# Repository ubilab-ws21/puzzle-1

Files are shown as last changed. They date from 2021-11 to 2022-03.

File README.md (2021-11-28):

# Divert power to machine room door (puzzle-1)
This puzzle is the first part of the 2021 ESCLAB.
According to that orange american man that once was US president, it's the best puzzle the world has ever seen.

## Objective
Divert the emergency power to the door that prevents you fom entering the second room.

## Story
There is some wiring on the wall. When you'll find some more panels to create the connection maybe you can divert the power to the door. Apparently the emergency power has not been used in ages.  
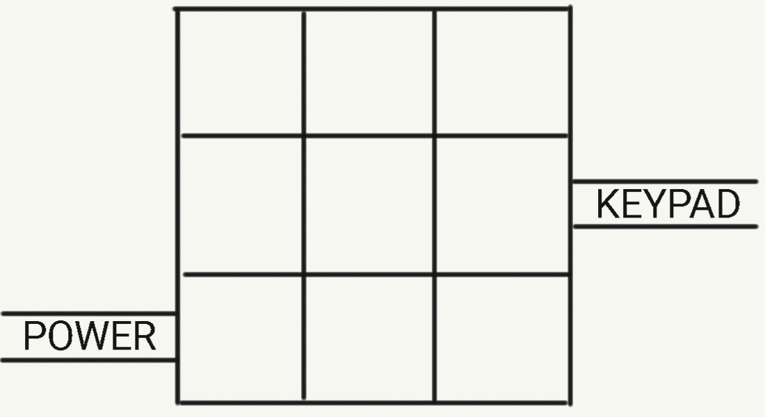
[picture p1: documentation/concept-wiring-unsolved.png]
  
You spot a cube on the table in the room thats sides look like panels that yould be used for that.  
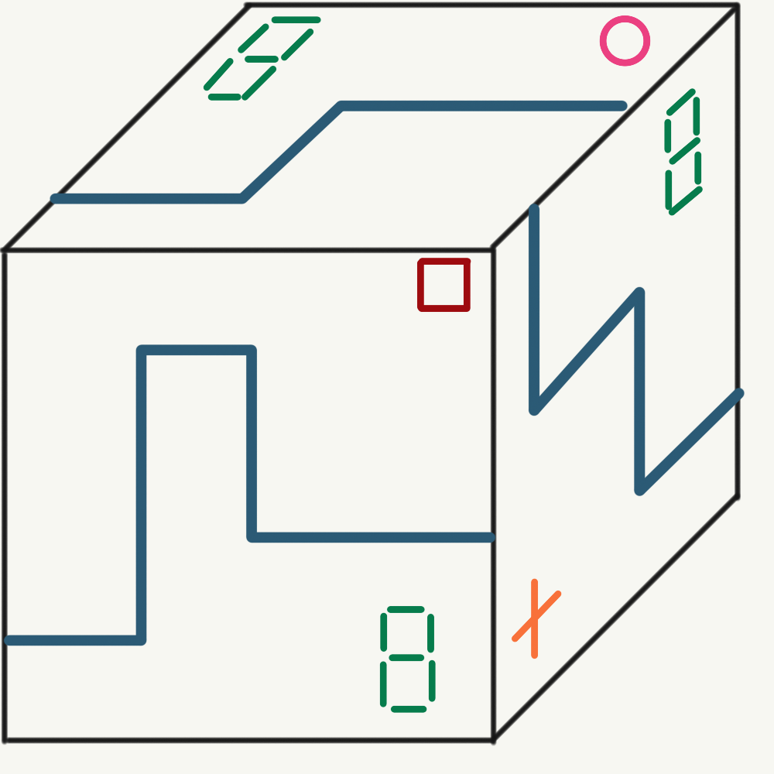
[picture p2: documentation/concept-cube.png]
  
Upon further inspection you see that the cube starts sparkling when moving it in the hand. Also there are weird symbols on each side.  
Also in the room there is some kind of comic, that has the symbols in the title and a hint "to the sun".  
Maybe placing the cube with the symbols of the comic towards the sun (top) in the correct order it will open.

After finishing the sequence the cube lights up greeen and suddenly the panels will unlatch so you can take 'em off.  
You solve the wire-maze, given by the panels and place them so the connection between "emergency power" and the keypad is created on the wall.  

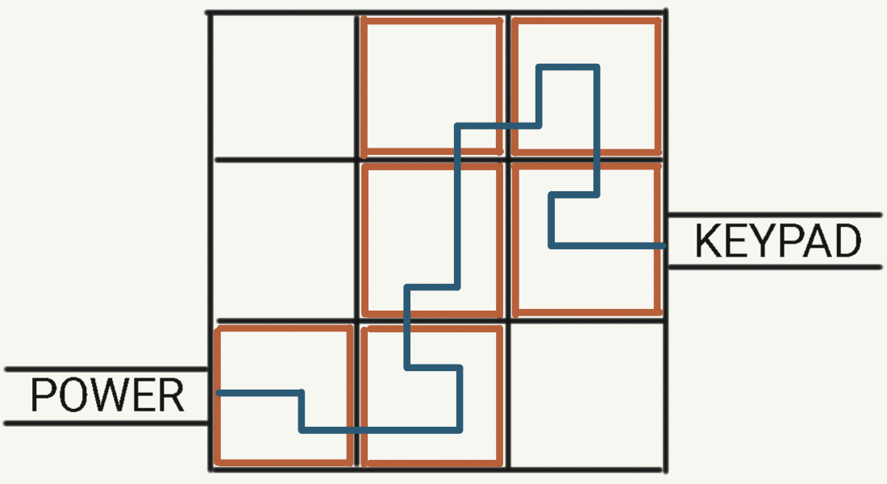
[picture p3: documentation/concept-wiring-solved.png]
  
The door opens and you step into the next room.

And then you die. Or maybe something nicer happens - that's up to the people doing the next puzzles. :)

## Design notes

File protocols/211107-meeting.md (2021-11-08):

# Protocol Meeting 07.11.2021	ESCLAB

**Autor**	Kevin Mader  
**Place & Time**	Kevin’s home, 16:00 – 20:15  
**Status**	Updated 08.11.2021  
**Attendees**	Alina, Sanjeev, Jonathan, Kevin  

## Topics

| Type | Content/Result | Name & Date |
|:----:| --- | --- |
| I |Update for Kevin about content of lab meeting from 04.11.2021<br>- Box to unlock the door to next room<br>- Has to be placed in a special orientation to be unlockable<br>- Unlocking by solving a wiring-challenge on the side of the box | |
| I | Rethinking game idea<br>- Box is small, therefore wiring -challenge would be (too) small<br>- No good story idea, why the wires should be on the box | |
| I | modification ideas for the game<br>- Box is small, therefore connection-challenge would be (too) small<br>- Insufficient ideas of how and why to orient the box<br>- Wiring could be “bypassing of a lock on the box”, not quite ubiquitous. | |
| I | Extending the game idea (Wiring)<br>- wiring-challenge will be part of the room<br>- creating the correct connection will enable the keypad at the door<br>- will be a more easy challenge<br>- box will contain needed components for wiring and has to be opened first | |
| I | Extending the game idea (design & unlocking of box)<br>- Box contains multi-color LEDs on all sides<br>- 6 Sides – 6 different Symbols<br>- Box has to be placed with the correct symbols up in a given order<br>- IDLE: Box is sleeping, no LED on.<br>- Moving the box: LEDs start to sparkle<br>- Correct placement: LEDs will flash green, then go back to sparkle<br>- Wrong placement: LEDs will flash red, lock input for x seconds.<br>- Correct order of input: LED will light up green in increasing intensity and then open. | |
| I | Updating the game idea #1 (Lazy as f* solution)<br>- Box will be simple box (wood) with a lid, containing wires for wiring-challenge | |
| I | Updating the game idea #2 (Fallback solution)<br>- Box will be simple box (wood) with a lid, containing square tiles used for wiring | |
| I | Updating the game idea #3 (Primary goal!)<br>- Box will be a 3D-printed box<br>- Side panels of the Box will be needed for wiring | |
| I | Recapitulation of presented Game-Idea
| I | Bill of materials has been written by hand | |
| T | Transfering BOM to octopart | Sanjeev, 11.11.2021 |
| T | Create Presentation of current game idea + initial 3D-Model for Cube | Kevin, 11.11.2021 |
| T | Writing down protocol | Kevin, 08.11.2021 |

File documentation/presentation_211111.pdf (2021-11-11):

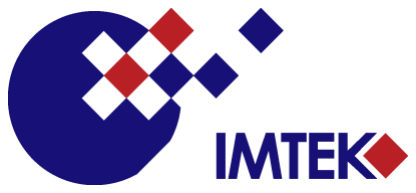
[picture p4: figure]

# Divert power to machine room door

Ubiquitous Lab - Escape Room - WS2122 11.11.2021
Institut für Mikrosystemtechnik - IMTEK Albert-Ludwigs-Universität Freiburg

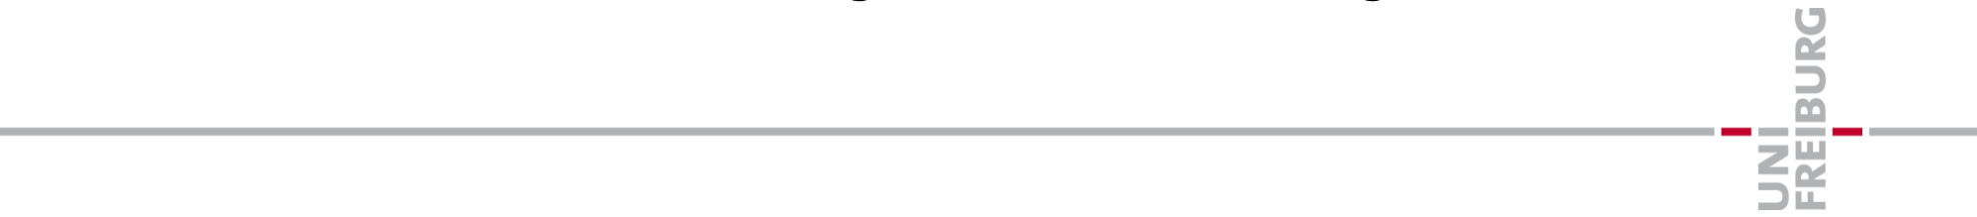
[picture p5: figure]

11.11.2021 | Kevin R. Mader

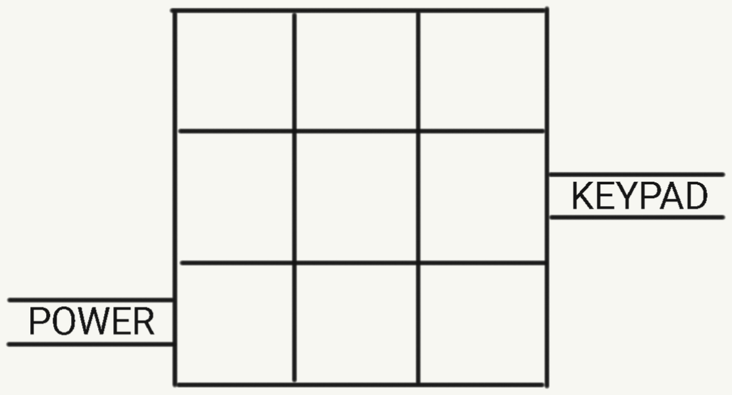
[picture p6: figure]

- 2 -

## Objective

- Divert power from USV to keypad via panel-puzzle on the wall
- 1. Find the Panels
- 2. Separate the Panels
- 3. Plug in the Panels
- 4. Enter the key code
- Enter the next room

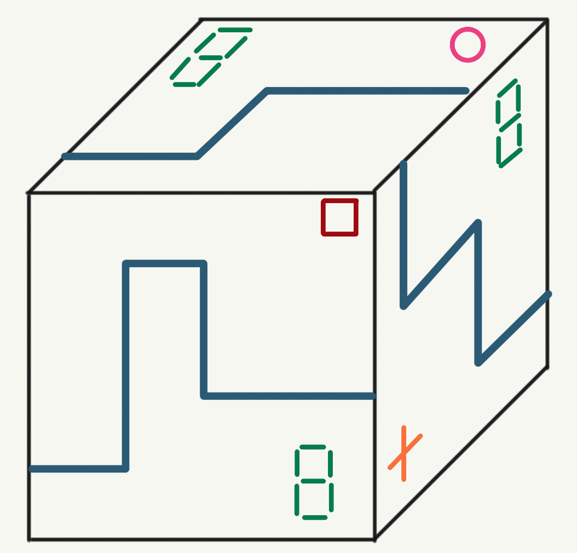
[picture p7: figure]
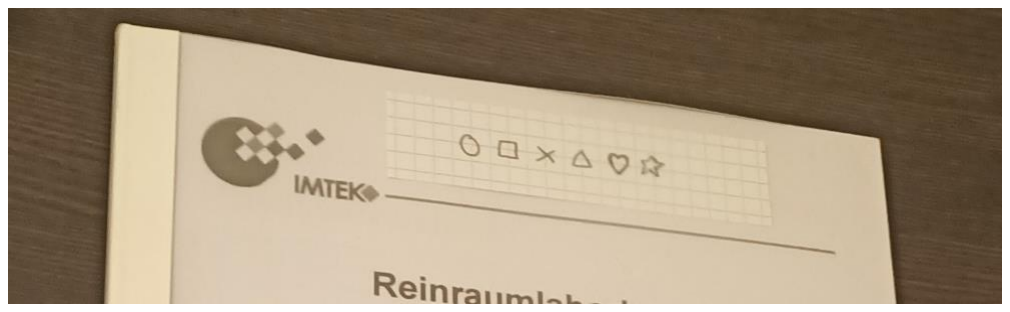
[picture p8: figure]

- 3 -

## Finding the Panels

- Mounted as a Cube
(Entrance door has not been needed a long time, so someone had some fun with them because they look nice.)
- Moving it makes it sparkle
- It has symbols on its sides
- The Symbols are on a document on the table in an order (e.g. comic, datasheet, ...)

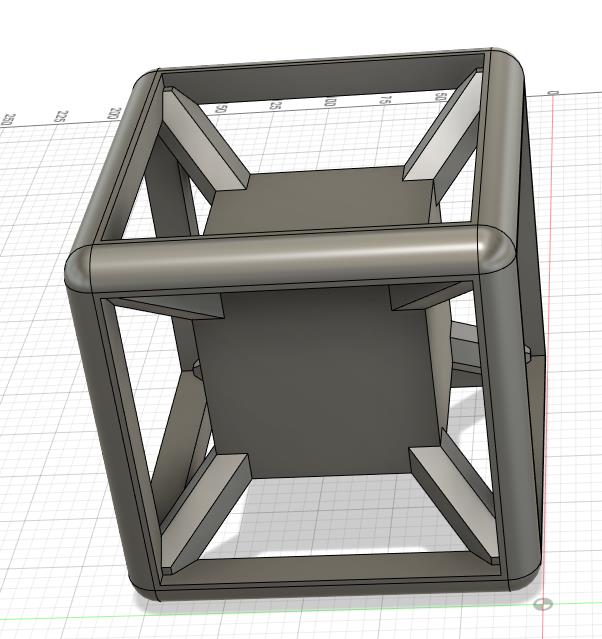
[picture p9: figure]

- 4 -

## Separating the Panels

- Moving the Cube makes it sparkle
- Placing it the correct way makes it flash green
- After finishing a sequence (given by symbols) a latch will release the panels so they can be taken out

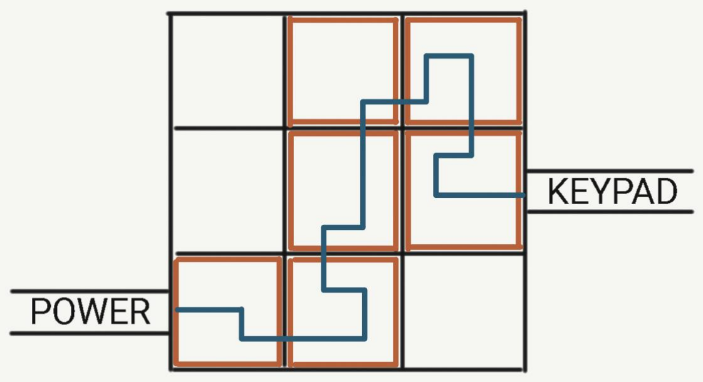
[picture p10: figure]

- 5 -

## Plug in the Panels

- Panels contain a maze
- Placing the mace so it will make connection from power to keypad
- Keypad will be aktivated
- The code can be displayed using 7-segment displays on the panels OR it can be gathered somewhere else

- 6 -

## Components / BOM

- Cube:
- 1x ESP8266 or ESP32
- 1x 3-Axis Gyroscope
- 1x stepper or servo motor
- 1x 3d-printed core with locking mechanism
- 6x 7-segment displays
- Multi-color LEDs, e.g. WS2812
- 6x 3d-printed panels (or maybe custom made PCB)
- 1x LiPo battery or stack of AA-Cells
- Wall
- 1x ESP8266 or ESP32
- 1x 3D-Printed receptables for panels
- General
- Magnets (?) for mechanical & electrical connection Alternatively Pin-header and 3D-printed locking pins
- Some wires and a lot of luck

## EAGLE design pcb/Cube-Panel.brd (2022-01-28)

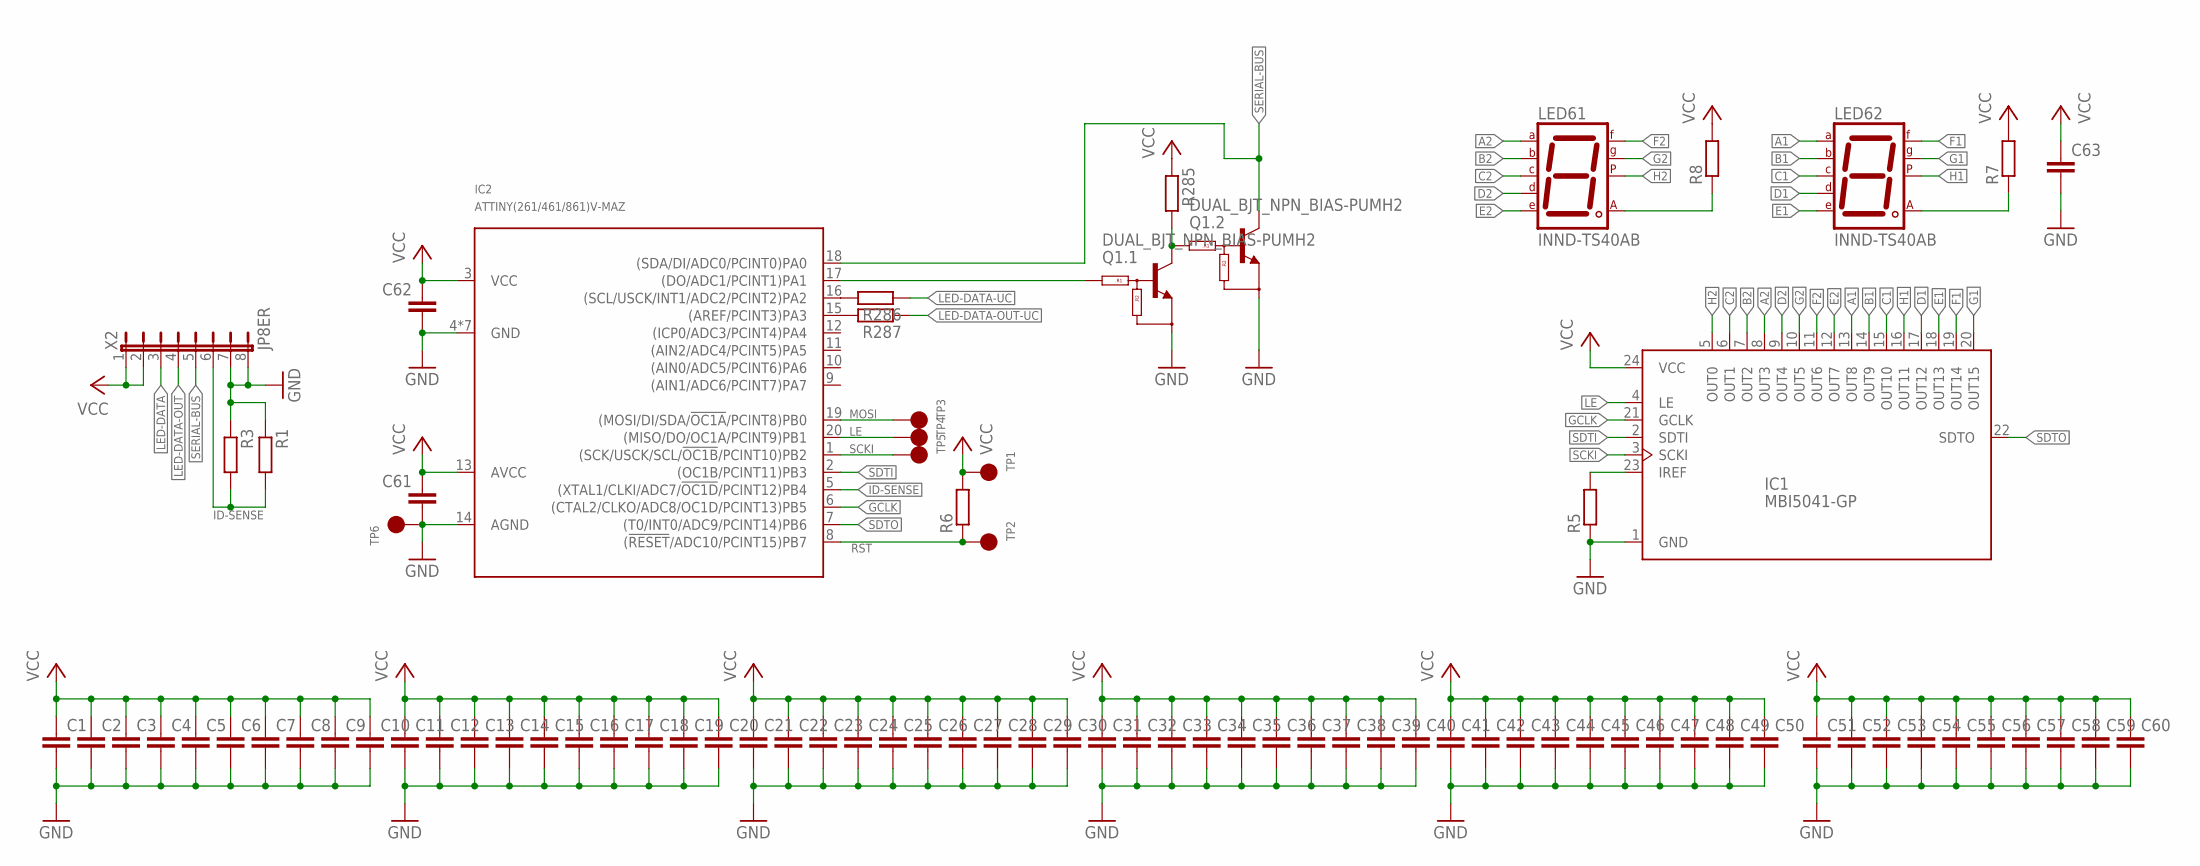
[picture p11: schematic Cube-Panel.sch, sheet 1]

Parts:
C1, C2, C3, C4, C5, C6, C7, C8, C9, C10, C11, C12, C13, C14, C15, C16, C17, C18, C19, C20, C21, C22, C23, C24, C25, C26, C27, C28, C29, C30, C31, C32, C33, C34, C35, C36, C37, C38, C39, C40, C41, C42, C43, C44, C45, C46, C47, C48, C49, C50, C51, C52, C53, C54, C55, C56, C57, C58, C59, C60, C61, C62, C63: KONDENSATOR-0603; 0603
IC1: MBI5041-GP; SSOP24-150-0.635
IC2: ATTINY(261/461/861)V-MAZ; QFN-20
LED61, LED62: INND-TS40AB; 7SEG-13
Q1: DUAL_BJT_NPN_BIAS-PUMH2; SOT-363(SC-88)
R1, R3, R5, R6, R7, R8, R285, R286, R287: WIDERSTAND-0603; 0603
TP1, TP2, TP3, TP4, TP5, TP6: TP; TP[1.5][R]
X2: JP8ER; JP8

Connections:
A1: IC1.13 (OUT8), LED62.10 (A)
A2: IC1.8 (OUT3), LED61.10 (A)
B1: IC1.14 (OUT9), LED62.9 (B)
B2: IC1.7 (OUT2), LED61.9 (B)
C1: IC1.15 (OUT10), LED62.8 (C)
C2: IC1.6 (OUT1), LED61.8 (C)
D1: IC1.17 (OUT12), LED62.5 (D)
D2: IC1.9 (OUT4), LED61.5 (D)
E1: IC1.18 (OUT13), LED62.1 (E)
E2: IC1.12 (OUT7), LED61.1 (E)
F1: IC1.19 (OUT14), LED62.2 (F)
F2: IC1.11 (OUT6), LED61.2 (F)
G1: IC1.20 (OUT15), LED62.3 (G)
G2: IC1.10 (OUT5), LED61.3 (G)
GCLK: IC1.21 (GCLK), IC2.6 ((CTAL2/CLKO/ADC8/OC1D/PCINT13)PB5)
GND: C1.P$2 (2), C2.P$2 (2), C3.P$2 (2), C4.P$2 (2), C5.P$2 (2), C6.P$2 (2), C7.P$2 (2), C8.P$2 (2), C9.P$2 (2), C10.P$2 (2), C11.P$2 (2), C12.P$2 (2), C13.P$2 (2), C14.P$2 (2), C15.P$2 (2), C16.P$2 (2), C17.P$2 (2), C18.P$2 (2), C19.P$2 (2), C20.P$2 (2), C21.P$2 (2), C22.P$2 (2), C23.P$2 (2), C24.P$2 (2), C25.P$2 (2), C26.P$2 (2), C27.P$2 (2), C28.P$2 (2), C29.P$2 (2), C30.P$2 (2), C31.P$2 (2), C32.P$2 (2), C33.P$2 (2), C34.P$2 (2), C35.P$2 (2), C36.P$2 (2), C37.P$2 (2), C38.P$2 (2), C39.P$2 (2), C40.P$2 (2), C41.P$2 (2), C42.P$2 (2), C43.P$2 (2), C44.P$2 (2), C45.P$2 (2), C46.P$2 (2), C47.P$2 (2), C48.P$2 (2), C49.P$2 (2), C50.P$2 (2), C51.P$2 (2), C52.P$2 (2), C53.P$2 (2), C54.P$2 (2), C55.P$2 (2), C56.P$2 (2), C57.P$2 (2), C58.P$2 (2), C59.P$2 (2), C60.P$2 (2), C61.P$2 (2), C62.P$2 (2), C63.P$2 (2), IC1.1 (GND), IC2.4 (GND), IC2.14 (AGND), IC2.PAD (GND), IC2.PAD$1 (GND), IC2.PAD$2 (GND), IC2.PAD$3 (GND), IC2.PAD$4 (GND), IC2.PAD$5 (GND), Q1.1 (E), Q1.4 (E), R1.P$1 (1), R3.P$1 (1), R5.P$1 (1), TP6.P$1, X2.7, X2.8; also elsewhere on the board
H1: IC1.16 (OUT11), LED62.7 (DP)
H2: IC1.5 (OUT0), LED61.7 (DP)
ID-SENSE: IC2.5 ((XTAL1/CLKI/ADC7/!OC1D!/PCINT12)PB4), R1.P$2 (2), R3.P$2 (2), X2.6
LE: IC1.4 (LE), IC2.20 ((MISO/DO/OC1A/PCINT9)PB1), TP4.P$1
LED-DATA: X2.3; also elsewhere on the board
LED-DATA-OUT: X2.4; also elsewhere on the board
LED-DATA-OUT-UC: R287.P$1 (1); also elsewhere on the board
LED-DATA-UC: R286.P$1 (1); also elsewhere on the board
MOSI: IC2.19 ((MOSI/DI/SDA/!OC1A!/PCINT8)PB0), TP3.P$1
unnamed: IC1.23 (IREF), R5.P$2 (2)
unnamed: IC2.16 ((SCL/USCK/INT1/ADC2/PCINT2)PA2), R286.P$2 (2)
unnamed: Q1.5 (B), Q1.6 (C), R285.P$2 (2)
unnamed: IC2.15 ((AREF/PCINT3)PA3), R287.P$2 (2)
unnamed: LED61.6 (CA2), R8.P$1 (1)
unnamed: LED62.6 (CA2), R7.P$1 (1)
RST: IC2.8 ((!RESET!/ADC10/PCINT15)PB7), R6.P$1 (1), TP2.P$1
SCKI: IC1.3 (SCKI), IC2.1 ((SCK/USCK/SCL/!OC1B!/PCINT10)PB2), TP5.P$1
SDTI: IC1.2 (SDTI), IC2.2 ((OC1B/PCINT11)PB3)
SDTO: IC1.22 (SDTO), IC2.7 ((T0/INT0/ADC9/PCINT14)PB6)
SERIAL-BUS: IC2.18 ((SDA/DI/ADC0/PCINT0)PA0), Q1.3 (C), X2.5
SERIAL-BUS-TX: IC2.17 ((DO/ADC1/PCINT1)PA1), Q1.2 (B)
VCC: C1.P$1 (1), C2.P$1 (1), C3.P$1 (1), C4.P$1 (1), C5.P$1 (1), C6.P$1 (1), C7.P$1 (1), C8.P$1 (1), C9.P$1 (1), C10.P$1 (1), C11.P$1 (1), C12.P$1 (1), C13.P$1 (1), C14.P$1 (1), C15.P$1 (1), C16.P$1 (1), C17.P$1 (1), C18.P$1 (1), C19.P$1 (1), C20.P$1 (1), C21.P$1 (1), C22.P$1 (1), C23.P$1 (1), C24.P$1 (1), C25.P$1 (1), C26.P$1 (1), C27.P$1 (1), C28.P$1 (1), C29.P$1 (1), C30.P$1 (1), C31.P$1 (1), C32.P$1 (1), C33.P$1 (1), C34.P$1 (1), C35.P$1 (1), C36.P$1 (1), C37.P$1 (1), C38.P$1 (1), C39.P$1 (1), C40.P$1 (1), C41.P$1 (1), C42.P$1 (1), C43.P$1 (1), C44.P$1 (1), C45.P$1 (1), C46.P$1 (1), C47.P$1 (1), C48.P$1 (1), C49.P$1 (1), C50.P$1 (1), C51.P$1 (1), C52.P$1 (1), C53.P$1 (1), C54.P$1 (1), C55.P$1 (1), C56.P$1 (1), C57.P$1 (1), C58.P$1 (1), C59.P$1 (1), C60.P$1 (1), C61.P$1 (1), C62.P$1 (1), C63.P$1 (1), IC1.24 (VCC), IC2.3 (VCC), IC2.13 (AVCC), R6.P$2 (2), R7.P$2 (2), R8.P$2 (2), R285.P$1 (1), TP1.P$1, X2.1, X2.2; also elsewhere on the board

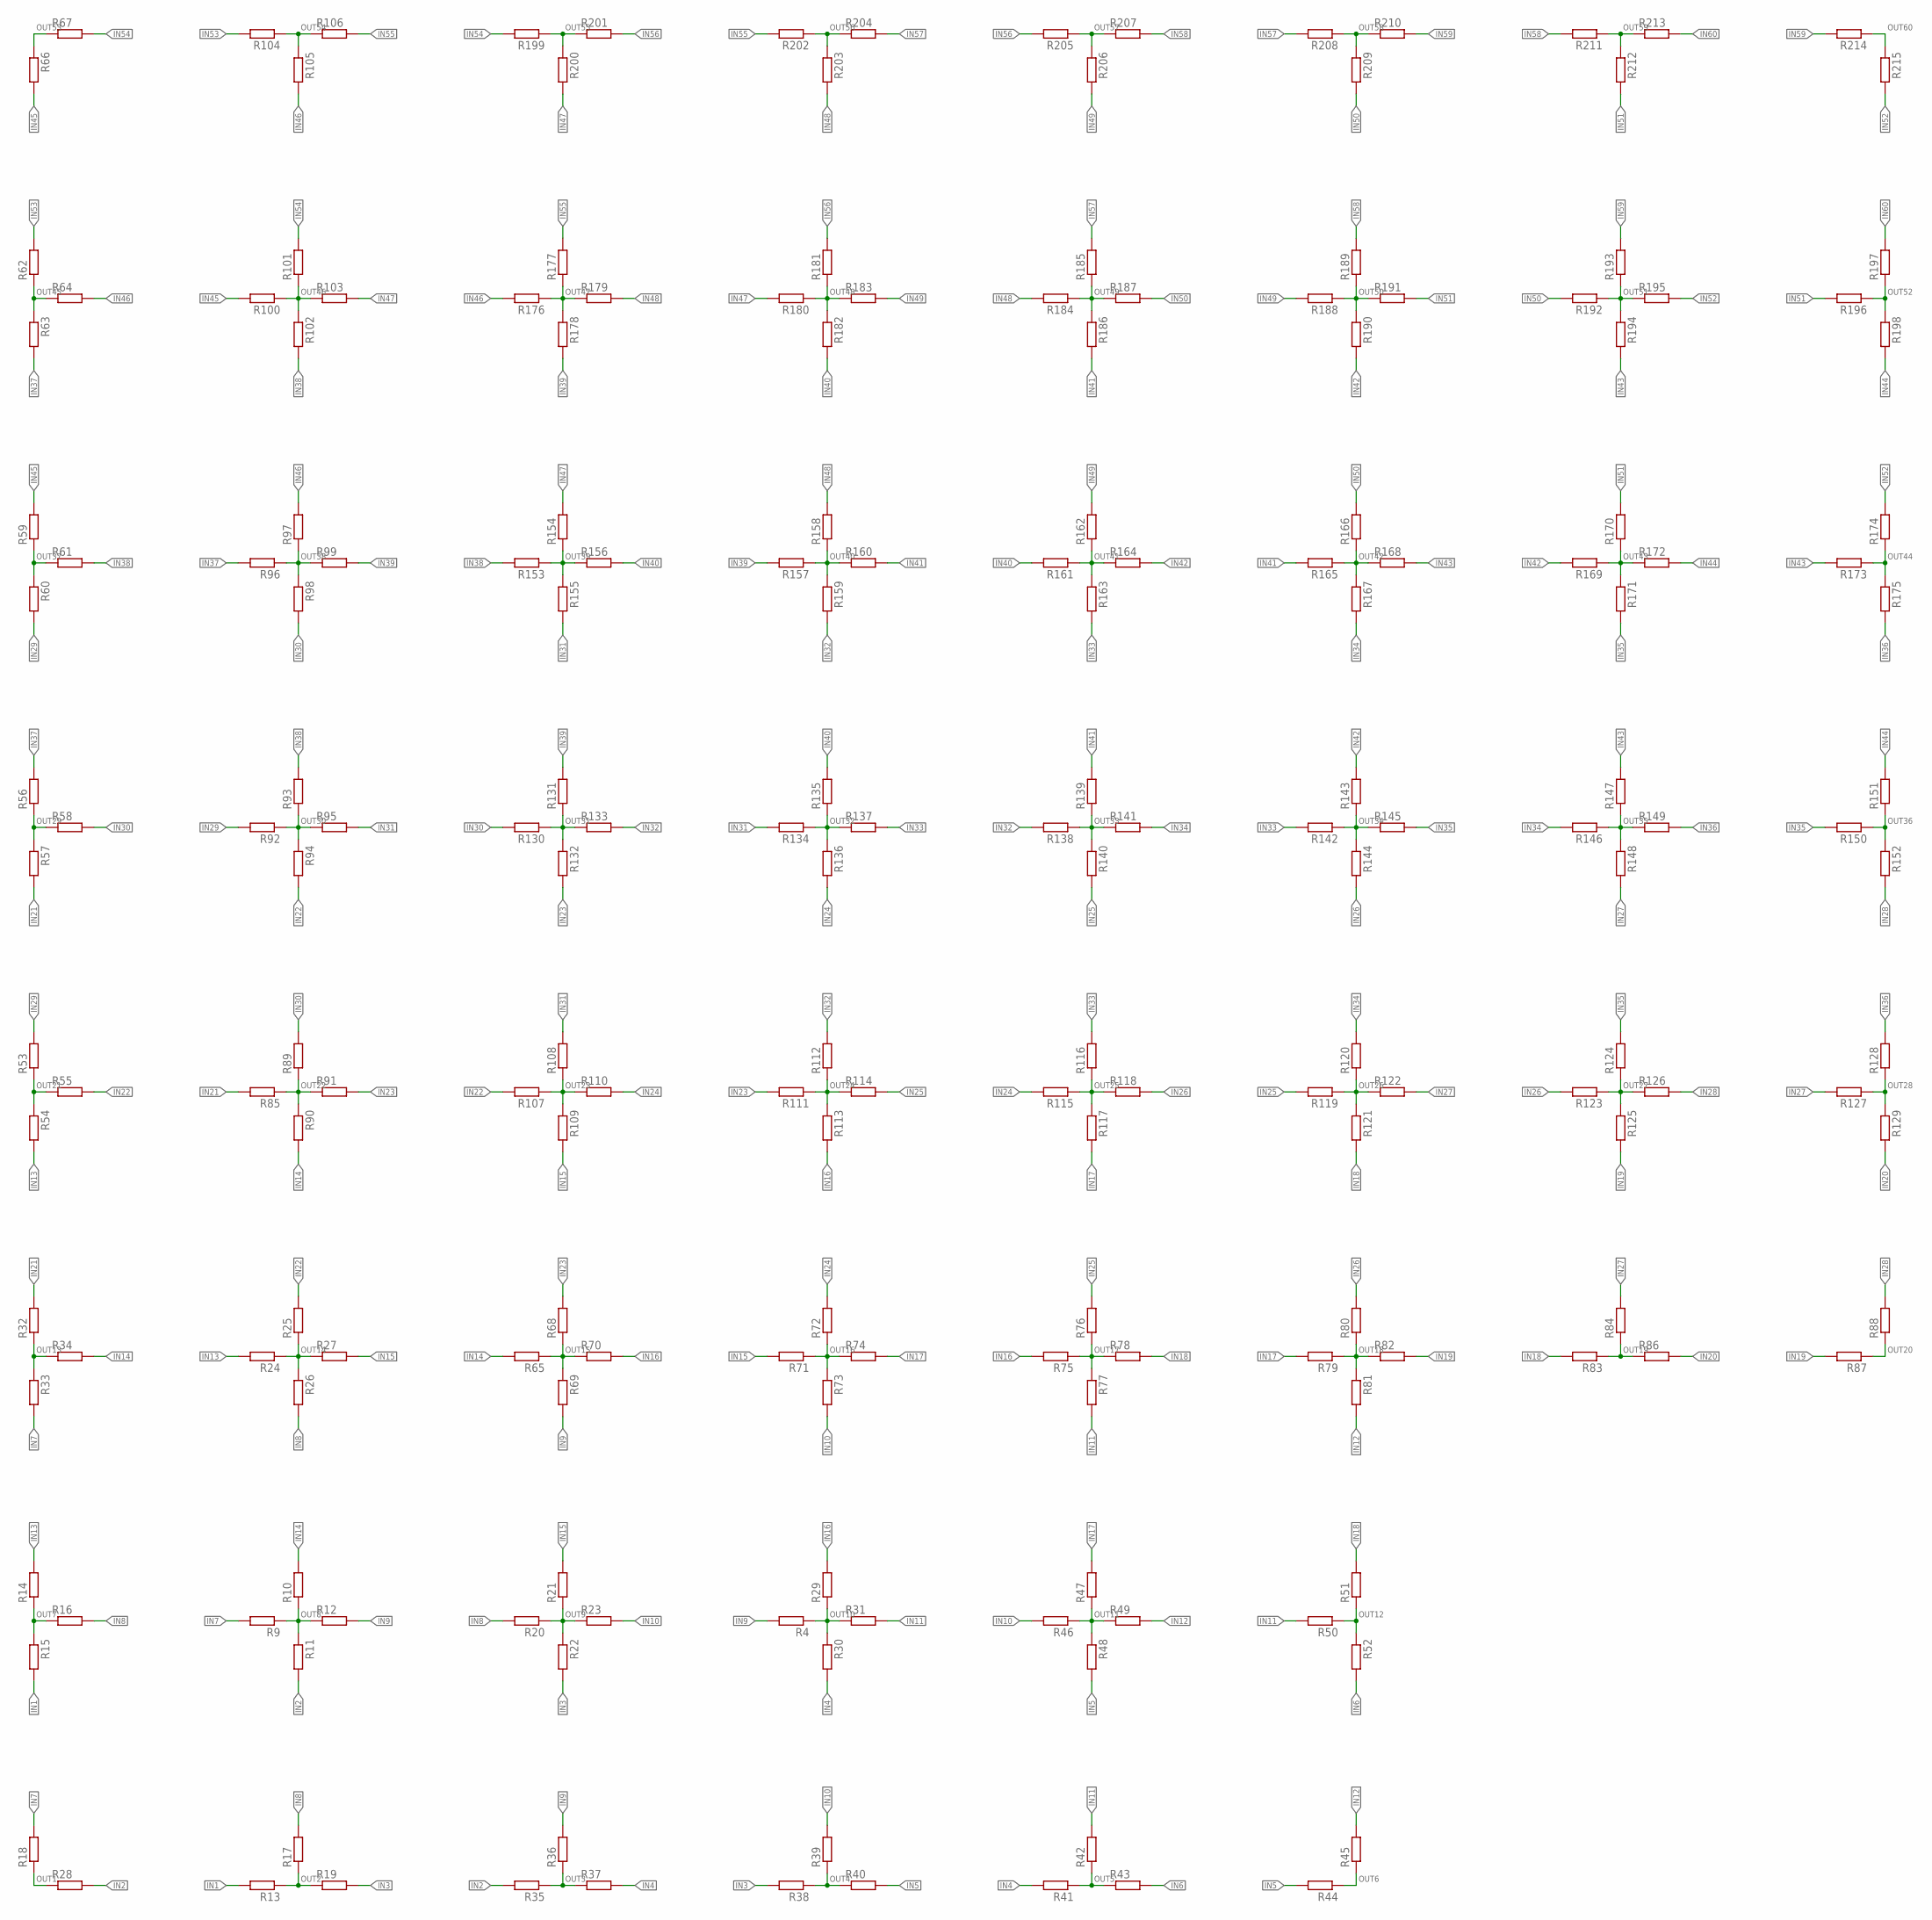
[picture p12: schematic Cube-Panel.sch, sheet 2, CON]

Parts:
R4, R9, R10, R11, R12, R13, R14, R15, R16, R17, R18, R19, R20, R21, R22, R23, R24, R25, R26, R27, R28, R29, R30, R31, R32, R33, R34, R35, R36, R37, R38, R39, R40, R41, R42, R43, R44, R45, R46, R47, R48, R49, R50, R51, R52, R53, R54, R55, R56, R57, R58, R59, R60, R61, R62, R63, R64, R65, R66, R67, R68, R69, R70, R71, R72, R73, R74, R75, R76, R77, R78, R79, R80, R81, R82, R83, R84, R85, R86, R87, R88, R89, R90, R91, R92, R93, R94, R95, R96, R97, R98, R99, R100, R101, R102, R103, R104, R105, R106, R107, R108, R109, R110, R111, R112, R113, R114, R115, R116, R117, R118, R119, R120, R121, R122, R123, R124, R125, R126, R127, R128, R129, R130, R131, R132, R133, R134, R135, R136, R137, R138, R139, R140, R141, R142, R143, R144, R145, R146, R147, R148, R149, R150, R151, R152, R153, R154, R155, R156, R157, R158, R159, R160, R161, R162, R163, R164, R165, R166, R167, R168, R169, R170, R171, R172, R173, R174, R175, R176, R177, R178, R179, R180, R181, R182, R183, R184, R185, R186, R187, R188, R189, R190, R191, R192, R193, R194, R195, R196, R197, R198, R199, R200, R201, R202, R203, R204, R205, R206, R207, R208, R209, R210, R211, R212, R213, R214, R215: WIDERSTAND-0603; 0603

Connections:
IN1: R13.P$2 (2), R15.P$2 (2); also elsewhere on the board
IN2: R11.P$2 (2), R28.P$2 (2), R35.P$2 (2); also elsewhere on the board
IN3: R19.P$2 (2), R22.P$2 (2), R38.P$2 (2); also elsewhere on the board
IN4: R30.P$2 (2), R37.P$2 (2), R41.P$2 (2); also elsewhere on the board
IN5: R40.P$2 (2), R44.P$2 (2), R48.P$2 (2); also elsewhere on the board
IN6: R43.P$2 (2), R52.P$2 (2); also elsewhere on the board
IN7: R9.P$2 (2), R18.P$2 (2), R33.P$2 (2); also elsewhere on the board
IN8: R16.P$2 (2), R17.P$2 (2), R20.P$2 (2), R26.P$2 (2); also elsewhere on the board
IN9: R4.P$2 (2), R12.P$2 (2), R36.P$2 (2), R69.P$2 (2); also elsewhere on the board
IN10: R23.P$2 (2), R39.P$2 (2), R46.P$2 (2), R73.P$2 (2); also elsewhere on the board
IN11: R31.P$2 (2), R42.P$2 (2), R50.P$2 (2), R77.P$2 (2); also elsewhere on the board
IN12: R45.P$2 (2), R49.P$2 (2), R81.P$2 (2); also elsewhere on the board
IN13: R14.P$2 (2), R24.P$2 (2), R54.P$2 (2); also elsewhere on the board
IN14: R10.P$2 (2), R34.P$2 (2), R65.P$2 (2), R90.P$2 (2); also elsewhere on the board
IN15: R21.P$2 (2), R27.P$2 (2), R71.P$2 (2), R109.P$2 (2); also elsewhere on the board
IN16: R29.P$2 (2), R70.P$2 (2), R75.P$2 (2), R113.P$2 (2); also elsewhere on the board
IN17: R47.P$2 (2), R74.P$2 (2), R79.P$2 (2), R117.P$2 (2); also elsewhere on the board
IN18: R51.P$2 (2), R78.P$2 (2), R83.P$2 (2), R121.P$2 (2); also elsewhere on the board
IN19: R82.P$2 (2), R87.P$2 (2), R125.P$2 (2); also elsewhere on the board
IN20: R86.P$2 (2), R129.P$2 (2); also elsewhere on the board
IN21: R32.P$2 (2), R57.P$2 (2), R85.P$2 (2); also elsewhere on the board
IN22: R25.P$2 (2), R55.P$2 (2), R94.P$2 (2), R107.P$2 (2); also elsewhere on the board
IN23: R68.P$2 (2), R91.P$2 (2), R111.P$2 (2), R132.P$2 (2); also elsewhere on the board
IN24: R72.P$2 (2), R110.P$2 (2), R115.P$2 (2), R136.P$2 (2); also elsewhere on the board
IN25: R76.P$2 (2), R114.P$2 (2), R119.P$2 (2), R140.P$2 (2); also elsewhere on the board
IN26: R80.P$2 (2), R118.P$2 (2), R123.P$2 (2), R144.P$2 (2); also elsewhere on the board
IN27: R84.P$2 (2), R122.P$2 (2), R127.P$2 (2), R148.P$2 (2); also elsewhere on the board
IN28: R88.P$2 (2), R126.P$2 (2), R152.P$2 (2); also elsewhere on the board
IN29: R53.P$2 (2), R60.P$2 (2), R92.P$2 (2); also elsewhere on the board
IN30: R58.P$2 (2), R89.P$2 (2), R98.P$2 (2), R130.P$2 (2); also elsewhere on the board
IN31: R95.P$2 (2), R108.P$2 (2), R134.P$2 (2), R155.P$2 (2); also elsewhere on the board
IN32: R112.P$2 (2), R133.P$2 (2), R138.P$2 (2), R159.P$2 (2); also elsewhere on the board
IN33: R116.P$2 (2), R137.P$2 (2), R142.P$2 (2), R163.P$2 (2); also elsewhere on the board
IN34: R120.P$2 (2), R141.P$2 (2), R146.P$2 (2), R167.P$2 (2); also elsewhere on the board
IN35: R124.P$2 (2), R145.P$2 (2), R150.P$2 (2), R171.P$2 (2); also elsewhere on the board
IN36: R128.P$2 (2), R149.P$2 (2), R175.P$2 (2); also elsewhere on the board
IN37: R56.P$2 (2), R63.P$2 (2), R96.P$2 (2); also elsewhere on the board
IN38: R61.P$2 (2), R93.P$2 (2), R102.P$2 (2), R153.P$2 (2); also elsewhere on the board
IN39: R99.P$2 (2), R131.P$2 (2), R157.P$2 (2), R178.P$2 (2); also elsewhere on the board
IN40: R135.P$2 (2), R156.P$2 (2), R161.P$2 (2), R182.P$2 (2); also elsewhere on the board
IN41: R139.P$2 (2), R160.P$2 (2), R165.P$2 (2), R186.P$2 (2); also elsewhere on the board
IN42: R143.P$2 (2), R164.P$2 (2), R169.P$2 (2), R190.P$2 (2); also elsewhere on the board
IN43: R147.P$2 (2), R168.P$2 (2), R173.P$2 (2), R194.P$2 (2); also elsewhere on the board
IN44: R151.P$2 (2), R172.P$2 (2), R198.P$2 (2); also elsewhere on the board
IN45: R59.P$2 (2), R66.P$2 (2), R100.P$2 (2); also elsewhere on the board
IN46: R64.P$2 (2), R97.P$2 (2), R105.P$2 (2), R176.P$2 (2); also elsewhere on the board
IN47: R103.P$2 (2), R154.P$2 (2), R180.P$2 (2), R200.P$2 (2); also elsewhere on the board
IN48: R158.P$2 (2), R179.P$2 (2), R184.P$2 (2), R203.P$2 (2); also elsewhere on the board
IN49: R162.P$2 (2), R183.P$2 (2), R188.P$2 (2), R206.P$2 (2); also elsewhere on the board
IN50: R166.P$2 (2), R187.P$2 (2), R192.P$2 (2), R209.P$2 (2); also elsewhere on the board
IN51: R170.P$2 (2), R191.P$2 (2), R196.P$2 (2), R212.P$2 (2); also elsewhere on the board
IN52: R174.P$2 (2), R195.P$2 (2), R215.P$2 (2); also elsewhere on the board
IN53: R62.P$2 (2), R104.P$2 (2); also elsewhere on the board
IN54: R67.P$2 (2), R101.P$2 (2), R199.P$2 (2); also elsewhere on the board
IN55: R106.P$2 (2), R177.P$2 (2), R202.P$2 (2); also elsewhere on the board
IN56: R181.P$2 (2), R201.P$2 (2), R205.P$2 (2); also elsewhere on the board
IN57: R185.P$2 (2), R204.P$2 (2), R208.P$2 (2); also elsewhere on the board
IN58: R189.P$2 (2), R207.P$2 (2), R211.P$2 (2); also elsewhere on the board
IN59: R193.P$2 (2), R210.P$2 (2), R214.P$2 (2); also elsewhere on the board
IN60: R197.P$2 (2), R213.P$2 (2); also elsewhere on the board
OUT1: R18.P$1 (1), R28.P$1 (1); also elsewhere on the board
OUT2: R13.P$1 (1), R17.P$1 (1), R19.P$1 (1); also elsewhere on the board
OUT3: R35.P$1 (1), R36.P$1 (1), R37.P$1 (1); also elsewhere on the board
OUT4: R38.P$1 (1), R39.P$1 (1), R40.P$1 (1); also elsewhere on the board
OUT5: R41.P$1 (1), R42.P$1 (1), R43.P$1 (1); also elsewhere on the board
OUT6: R44.P$1 (1), R45.P$1 (1); also elsewhere on the board
OUT7: R14.P$1 (1), R15.P$1 (1), R16.P$1 (1); also elsewhere on the board
OUT8: R9.P$1 (1), R10.P$1 (1), R11.P$1 (1), R12.P$1 (1); also elsewhere on the board
OUT9: R20.P$1 (1), R21.P$1 (1), R22.P$1 (1), R23.P$1 (1); also elsewhere on the board
OUT10: R4.P$1 (1), R29.P$1 (1), R30.P$1 (1), R31.P$1 (1); also elsewhere on the board
OUT11: R46.P$1 (1), R47.P$1 (1), R48.P$1 (1), R49.P$1 (1); also elsewhere on the board
OUT12: R50.P$1 (1), R51.P$1 (1), R52.P$1 (1); also elsewhere on the board
OUT13: R32.P$1 (1), R33.P$1 (1), R34.P$1 (1); also elsewhere on the board
OUT14: R24.P$1 (1), R25.P$1 (1), R26.P$1 (1), R27.P$1 (1); also elsewhere on the board
OUT15: R65.P$1 (1), R68.P$1 (1), R69.P$1 (1), R70.P$1 (1); also elsewhere on the board
OUT16: R71.P$1 (1), R72.P$1 (1), R73.P$1 (1), R74.P$1 (1); also elsewhere on the board
OUT17: R75.P$1 (1), R76.P$1 (1), R77.P$1 (1), R78.P$1 (1); also elsewhere on the board
OUT18: R79.P$1 (1), R80.P$1 (1), R81.P$1 (1), R82.P$1 (1); also elsewhere on the board
OUT19: R83.P$1 (1), R84.P$1 (1), R86.P$1 (1); also elsewhere on the board
OUT20: R87.P$1 (1), R88.P$1 (1); also elsewhere on the board
OUT21: R53.P$1 (1), R54.P$1 (1), R55.P$1 (1); also elsewhere on the board
OUT22: R85.P$1 (1), R89.P$1 (1), R90.P$1 (1), R91.P$1 (1); also elsewhere on the board
OUT23: R107.P$1 (1), R108.P$1 (1), R109.P$1 (1), R110.P$1 (1); also elsewhere on the board
OUT24: R111.P$1 (1), R112.P$1 (1), R113.P$1 (1), R114.P$1 (1); also elsewhere on the board
OUT25: R115.P$1 (1), R116.P$1 (1), R117.P$1 (1), R118.P$1 (1); also elsewhere on the board
OUT26: R119.P$1 (1), R120.P$1 (1), R121.P$1 (1), R122.P$1 (1); also elsewhere on the board
OUT27: R123.P$1 (1), R124.P$1 (1), R125.P$1 (1), R126.P$1 (1); also elsewhere on the board
OUT28: R127.P$1 (1), R128.P$1 (1), R129.P$1 (1); also elsewhere on the board
OUT29: R56.P$1 (1), R57.P$1 (1), R58.P$1 (1); also elsewhere on the board
OUT30: R92.P$1 (1), R93.P$1 (1), R94.P$1 (1), R95.P$1 (1); also elsewhere on the board
OUT31: R130.P$1 (1), R131.P$1 (1), R132.P$1 (1), R133.P$1 (1); also elsewhere on the board
OUT32: R134.P$1 (1), R135.P$1 (1), R136.P$1 (1), R137.P$1 (1); also elsewhere on the board
OUT33: R138.P$1 (1), R139.P$1 (1), R140.P$1 (1), R141.P$1 (1); also elsewhere on the board
OUT34: R142.P$1 (1), R143.P$1 (1), R144.P$1 (1), R145.P$1 (1); also elsewhere on the board
OUT35: R146.P$1 (1), R147.P$1 (1), R148.P$1 (1), R149.P$1 (1); also elsewhere on the board
OUT36: R150.P$1 (1), R151.P$1 (1), R152.P$1 (1); also elsewhere on the board
OUT37: R59.P$1 (1), R60.P$1 (1), R61.P$1 (1); also elsewhere on the board
OUT38: R96.P$1 (1), R97.P$1 (1), R98.P$1 (1), R99.P$1 (1); also elsewhere on the board
OUT39: R153.P$1 (1), R154.P$1 (1), R155.P$1 (1), R156.P$1 (1); also elsewhere on the board
OUT40: R157.P$1 (1), R158.P$1 (1), R159.P$1 (1), R160.P$1 (1); also elsewhere on the board
OUT41: R161.P$1 (1), R162.P$1 (1), R163.P$1 (1), R164.P$1 (1); also elsewhere on the board
OUT42: R165.P$1 (1), R166.P$1 (1), R167.P$1 (1), R168.P$1 (1); also elsewhere on the board
OUT43: R169.P$1 (1), R170.P$1 (1), R171.P$1 (1), R172.P$1 (1); also elsewhere on the board
OUT44: R173.P$1 (1), R174.P$1 (1), R175.P$1 (1); also elsewhere on the board
OUT45: R62.P$1 (1), R63.P$1 (1), R64.P$1 (1); also elsewhere on the board
OUT46: R100.P$1 (1), R101.P$1 (1), R102.P$1 (1), R103.P$1 (1); also elsewhere on the board
OUT47: R176.P$1 (1), R177.P$1 (1), R178.P$1 (1), R179.P$1 (1); also elsewhere on the board
OUT48: R180.P$1 (1), R181.P$1 (1), R182.P$1 (1), R183.P$1 (1); also elsewhere on the board
OUT49: R184.P$1 (1), R185.P$1 (1), R186.P$1 (1), R187.P$1 (1); also elsewhere on the board
OUT50: R188.P$1 (1), R189.P$1 (1), R190.P$1 (1), R191.P$1 (1); also elsewhere on the board
OUT51: R192.P$1 (1), R193.P$1 (1), R194.P$1 (1), R195.P$1 (1); also elsewhere on the board
OUT52: R196.P$1 (1), R197.P$1 (1), R198.P$1 (1); also elsewhere on the board
OUT53: R66.P$1 (1), R67.P$1 (1); also elsewhere on the board
OUT54: R104.P$1 (1), R105.P$1 (1), R106.P$1 (1); also elsewhere on the board
OUT55: R199.P$1 (1), R200.P$1 (1), R201.P$1 (1); also elsewhere on the board
OUT56: R202.P$1 (1), R203.P$1 (1), R204.P$1 (1); also elsewhere on the board
OUT57: R205.P$1 (1), R206.P$1 (1), R207.P$1 (1); also elsewhere on the board
OUT58: R208.P$1 (1), R209.P$1 (1), R210.P$1 (1); also elsewhere on the board
OUT59: R211.P$1 (1), R212.P$1 (1), R213.P$1 (1); also elsewhere on the board
OUT60: R214.P$1 (1), R215.P$1 (1); also elsewhere on the board

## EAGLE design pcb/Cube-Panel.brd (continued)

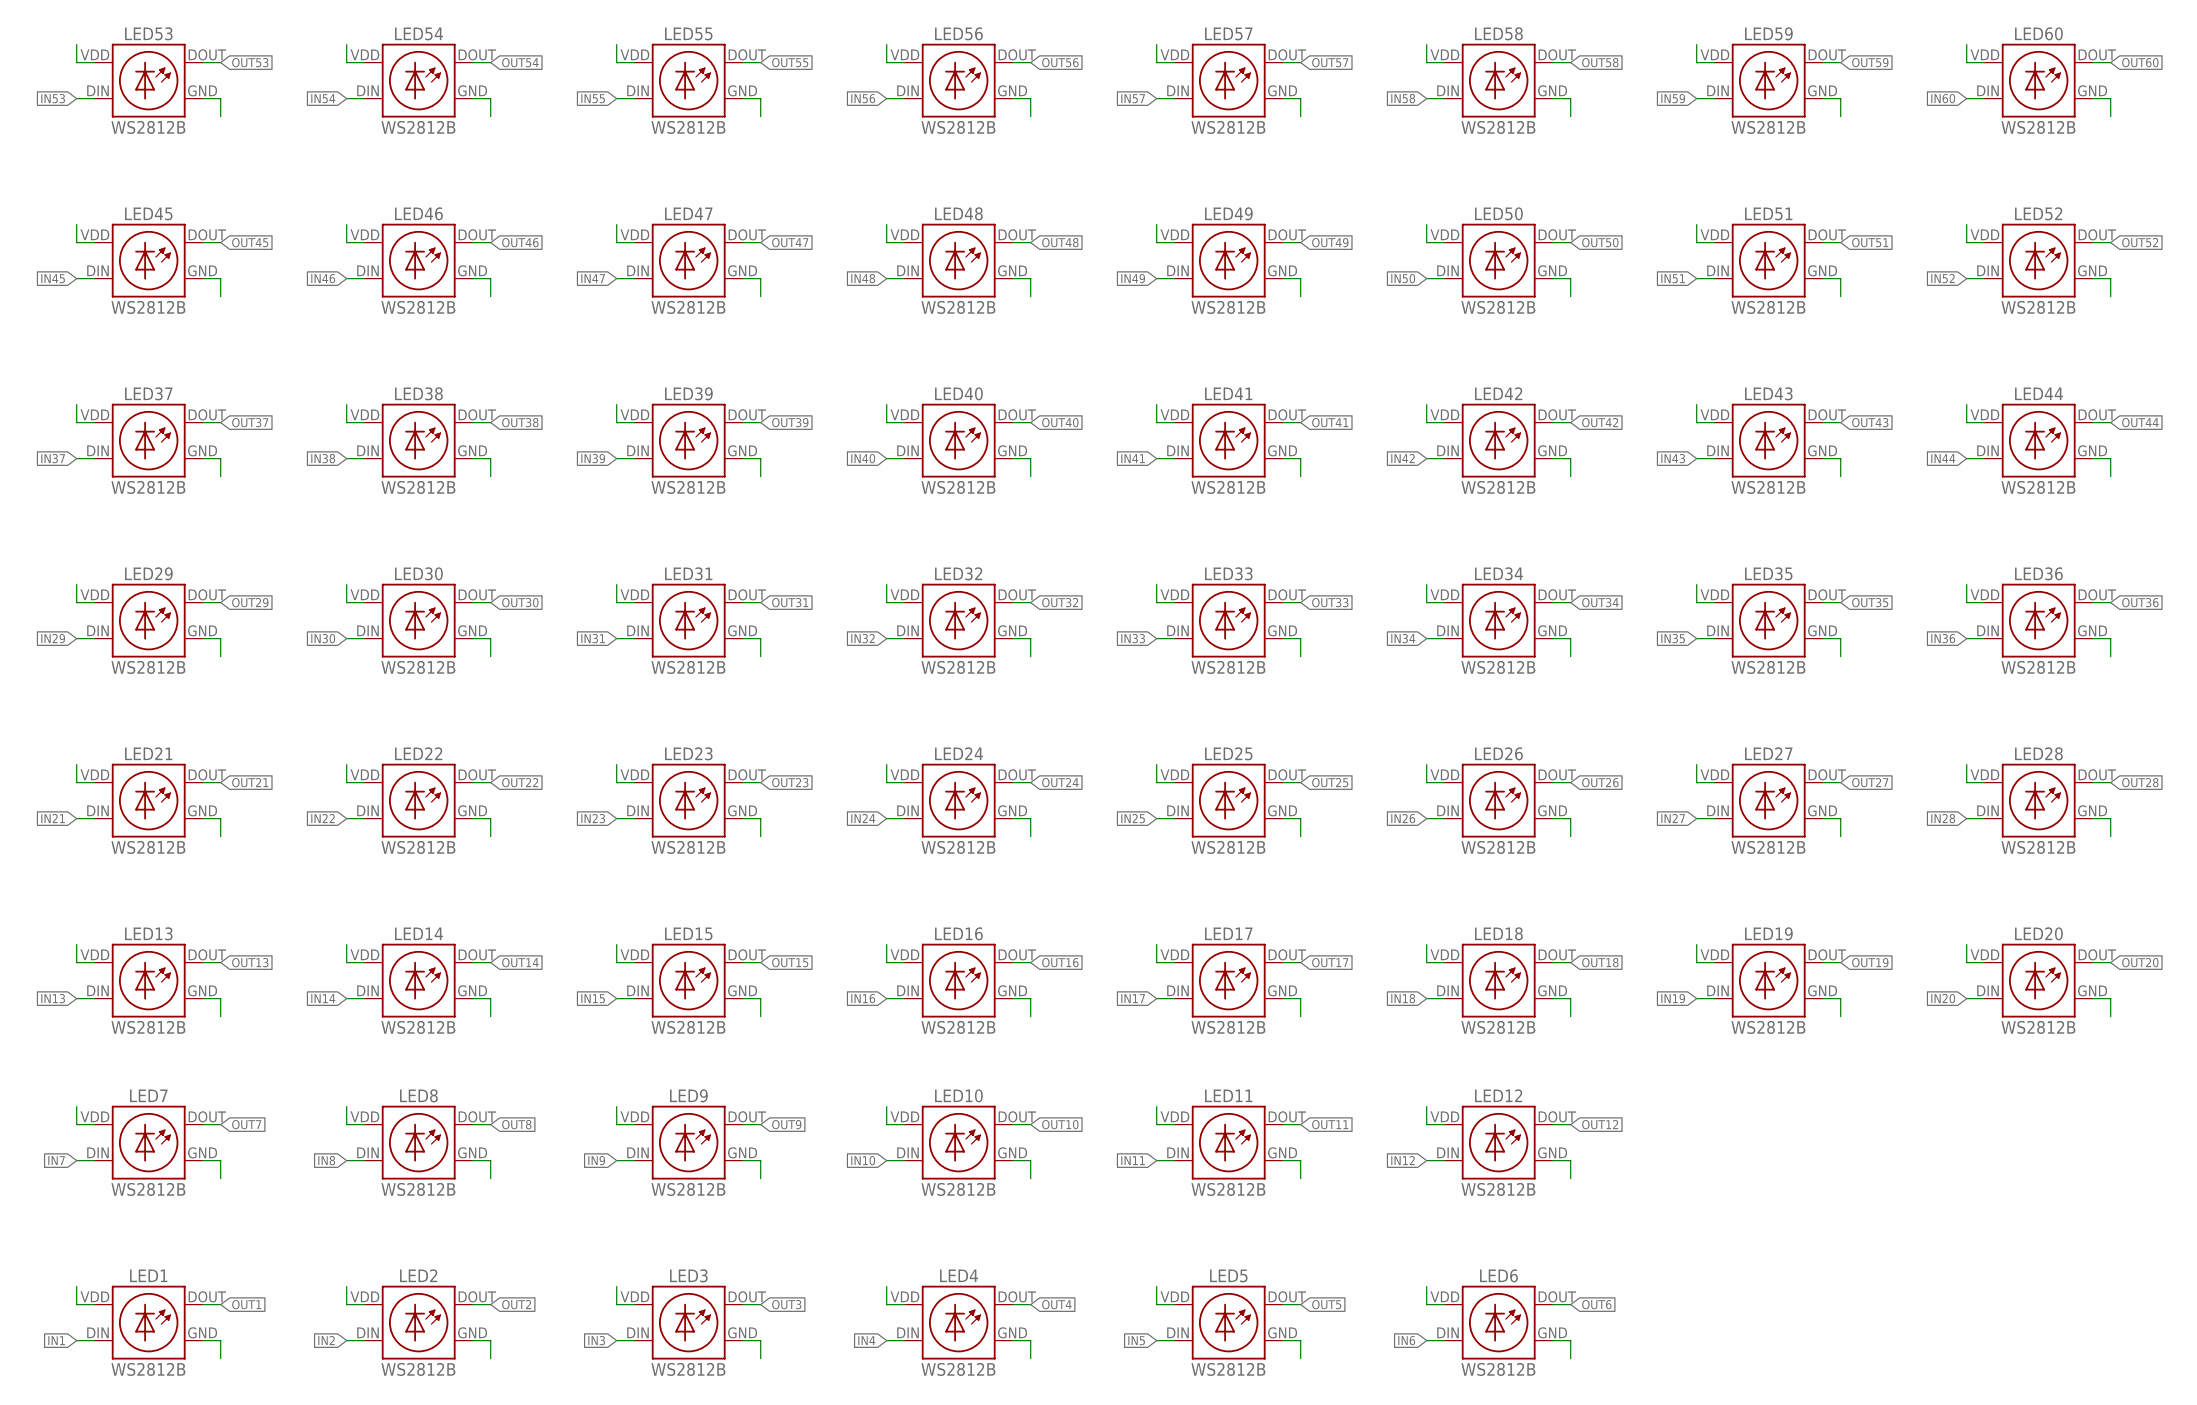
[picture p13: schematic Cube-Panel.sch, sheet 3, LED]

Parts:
LED1, LED2, LED3, LED4, LED5, LED6, LED7, LED8, LED9, LED10, LED11, LED12, LED13, LED14, LED15, LED16, LED17, LED18, LED19, LED20, LED21, LED22, LED23, LED24, LED25, LED26, LED27, LED28, LED29, LED30, LED31, LED32, LED33, LED34, LED35, LED36, LED37, LED38, LED39, LED40, LED41, LED42, LED43, LED44, LED45, LED46, LED47, LED48, LED49, LED50, LED51, LED52, LED53, LED54, LED55, LED56, LED57, LED58, LED59, LED60: WS2812B

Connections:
GND: LED1.GND, LED2.GND, LED3.GND, LED4.GND, LED5.GND, LED6.GND, LED7.GND, LED8.GND, LED9.GND, LED10.GND, LED11.GND, LED12.GND, LED13.GND, LED14.GND, LED15.GND, LED16.GND, LED17.GND, LED18.GND, LED19.GND, LED20.GND, LED21.GND, LED22.GND, LED23.GND, LED24.GND, LED25.GND, LED26.GND, LED27.GND, LED28.GND, LED29.GND, LED30.GND, LED31.GND, LED32.GND, LED33.GND, LED34.GND, LED35.GND, LED36.GND, LED37.GND, LED38.GND, LED39.GND, LED40.GND, LED41.GND, LED42.GND, LED43.GND, LED44.GND, LED45.GND, LED46.GND, LED47.GND, LED48.GND, LED49.GND, LED50.GND, LED51.GND, LED52.GND, LED53.GND, LED54.GND, LED55.GND, LED56.GND, LED57.GND, LED58.GND, LED59.GND, LED60.GND; also elsewhere on the board
IN1: LED1.DIN; also elsewhere on the board
IN2: LED2.DIN; also elsewhere on the board
IN3: LED3.DIN; also elsewhere on the board
IN4: LED4.DIN; also elsewhere on the board
IN5: LED5.DIN; also elsewhere on the board
IN6: LED6.DIN; also elsewhere on the board
IN7: LED7.DIN; also elsewhere on the board
IN8: LED8.DIN; also elsewhere on the board
IN9: LED9.DIN; also elsewhere on the board
IN10: LED10.DIN; also elsewhere on the board
IN11: LED11.DIN; also elsewhere on the board
IN12: LED12.DIN; also elsewhere on the board
IN13: LED13.DIN; also elsewhere on the board
IN14: LED14.DIN; also elsewhere on the board
IN15: LED15.DIN; also elsewhere on the board
IN16: LED16.DIN; also elsewhere on the board
IN17: LED17.DIN; also elsewhere on the board
IN18: LED18.DIN; also elsewhere on the board
IN19: LED19.DIN; also elsewhere on the board
IN20: LED20.DIN; also elsewhere on the board
IN21: LED21.DIN; also elsewhere on the board
IN22: LED22.DIN; also elsewhere on the board
IN23: LED23.DIN; also elsewhere on the board
IN24: LED24.DIN; also elsewhere on the board
IN25: LED25.DIN; also elsewhere on the board
IN26: LED26.DIN; also elsewhere on the board
IN27: LED27.DIN; also elsewhere on the board
IN28: LED28.DIN; also elsewhere on the board
IN29: LED29.DIN; also elsewhere on the board
IN30: LED30.DIN; also elsewhere on the board
IN31: LED31.DIN; also elsewhere on the board
IN32: LED32.DIN; also elsewhere on the board
IN33: LED33.DIN; also elsewhere on the board
IN34: LED34.DIN; also elsewhere on the board
IN35: LED35.DIN; also elsewhere on the board
IN36: LED36.DIN; also elsewhere on the board
IN37: LED37.DIN; also elsewhere on the board
IN38: LED38.DIN; also elsewhere on the board
IN39: LED39.DIN; also elsewhere on the board
IN40: LED40.DIN; also elsewhere on the board
IN41: LED41.DIN; also elsewhere on the board
IN42: LED42.DIN; also elsewhere on the board
IN43: LED43.DIN; also elsewhere on the board
IN44: LED44.DIN; also elsewhere on the board
IN45: LED45.DIN; also elsewhere on the board
IN46: LED46.DIN; also elsewhere on the board
IN47: LED47.DIN; also elsewhere on the board
IN48: LED48.DIN; also elsewhere on the board
IN49: LED49.DIN; also elsewhere on the board
IN50: LED50.DIN; also elsewhere on the board
IN51: LED51.DIN; also elsewhere on the board
IN52: LED52.DIN; also elsewhere on the board
IN53: LED53.DIN; also elsewhere on the board
IN54: LED54.DIN; also elsewhere on the board
IN55: LED55.DIN; also elsewhere on the board
IN56: LED56.DIN; also elsewhere on the board
IN57: LED57.DIN; also elsewhere on the board
IN58: LED58.DIN; also elsewhere on the board
IN59: LED59.DIN; also elsewhere on the board
IN60: LED60.DIN; also elsewhere on the board
OUT1: LED1.DOUT; also elsewhere on the board
OUT2: LED2.DOUT; also elsewhere on the board
OUT3: LED3.DOUT; also elsewhere on the board
OUT4: LED4.DOUT; also elsewhere on the board
OUT5: LED5.DOUT; also elsewhere on the board
OUT6: LED6.DOUT; also elsewhere on the board
OUT7: LED7.DOUT; also elsewhere on the board
OUT8: LED8.DOUT; also elsewhere on the board
OUT9: LED9.DOUT; also elsewhere on the board
OUT10: LED10.DOUT; also elsewhere on the board
OUT11: LED11.DOUT; also elsewhere on the board
OUT12: LED12.DOUT; also elsewhere on the board
OUT13: LED13.DOUT; also elsewhere on the board
OUT14: LED14.DOUT; also elsewhere on the board
OUT15: LED15.DOUT; also elsewhere on the board
OUT16: LED16.DOUT; also elsewhere on the board
OUT17: LED17.DOUT; also elsewhere on the board
OUT18: LED18.DOUT; also elsewhere on the board
OUT19: LED19.DOUT; also elsewhere on the board
OUT20: LED20.DOUT; also elsewhere on the board
OUT21: LED21.DOUT; also elsewhere on the board
OUT22: LED22.DOUT; also elsewhere on the board
OUT23: LED23.DOUT; also elsewhere on the board
OUT24: LED24.DOUT; also elsewhere on the board
OUT25: LED25.DOUT; also elsewhere on the board
OUT26: LED26.DOUT; also elsewhere on the board
OUT27: LED27.DOUT; also elsewhere on the board
OUT28: LED28.DOUT; also elsewhere on the board
OUT29: LED29.DOUT; also elsewhere on the board
OUT30: LED30.DOUT; also elsewhere on the board
OUT31: LED31.DOUT; also elsewhere on the board
OUT32: LED32.DOUT; also elsewhere on the board
OUT33: LED33.DOUT; also elsewhere on the board
OUT34: LED34.DOUT; also elsewhere on the board
OUT35: LED35.DOUT; also elsewhere on the board
OUT36: LED36.DOUT; also elsewhere on the board
OUT37: LED37.DOUT; also elsewhere on the board
OUT38: LED38.DOUT; also elsewhere on the board
OUT39: LED39.DOUT; also elsewhere on the board
OUT40: LED40.DOUT; also elsewhere on the board
OUT41: LED41.DOUT; also elsewhere on the board
OUT42: LED42.DOUT; also elsewhere on the board
OUT43: LED43.DOUT; also elsewhere on the board
OUT44: LED44.DOUT; also elsewhere on the board
OUT45: LED45.DOUT; also elsewhere on the board
OUT46: LED46.DOUT; also elsewhere on the board
OUT47: LED47.DOUT; also elsewhere on the board
OUT48: LED48.DOUT; also elsewhere on the board
OUT49: LED49.DOUT; also elsewhere on the board
OUT50: LED50.DOUT; also elsewhere on the board
OUT51: LED51.DOUT; also elsewhere on the board
OUT52: LED52.DOUT; also elsewhere on the board
OUT53: LED53.DOUT; also elsewhere on the board
OUT54: LED54.DOUT; also elsewhere on the board
OUT55: LED55.DOUT; also elsewhere on the board
OUT56: LED56.DOUT; also elsewhere on the board
OUT57: LED57.DOUT; also elsewhere on the board
OUT58: LED58.DOUT; also elsewhere on the board
OUT59: LED59.DOUT; also elsewhere on the board
OUT60: LED60.DOUT; also elsewhere on the board
VCC: LED1.VDD (VCC), LED2.VDD (VCC), LED3.VDD (VCC), LED4.VDD (VCC), LED5.VDD (VCC), LED6.VDD (VCC), LED7.VDD (VCC), LED8.VDD (VCC), LED9.VDD (VCC), LED10.VDD (VCC), LED11.VDD (VCC), LED12.VDD (VCC), LED13.VDD (VCC), LED14.VDD (VCC), LED15.VDD (VCC), LED16.VDD (VCC), LED17.VDD (VCC), LED18.VDD (VCC), LED19.VDD (VCC), LED20.VDD (VCC), LED21.VDD (VCC), LED22.VDD (VCC), LED23.VDD (VCC), LED24.VDD (VCC), LED25.VDD (VCC), LED26.VDD (VCC), LED27.VDD (VCC), LED28.VDD (VCC), LED29.VDD (VCC), LED30.VDD (VCC), LED31.VDD (VCC), LED32.VDD (VCC), LED33.VDD (VCC), LED34.VDD (VCC), LED35.VDD (VCC), LED36.VDD (VCC), LED37.VDD (VCC), LED38.VDD (VCC), LED39.VDD (VCC), LED40.VDD (VCC), LED41.VDD (VCC), LED42.VDD (VCC), LED43.VDD (VCC), LED44.VDD (VCC), LED45.VDD (VCC), LED46.VDD (VCC), LED47.VDD (VCC), LED48.VDD (VCC), LED49.VDD (VCC), LED50.VDD (VCC), LED51.VDD (VCC), LED52.VDD (VCC), LED53.VDD (VCC), LED54.VDD (VCC), LED55.VDD (VCC), LED56.VDD (VCC), LED57.VDD (VCC), LED58.VDD (VCC), LED59.VDD (VCC), LED60.VDD (VCC); also elsewhere on the board

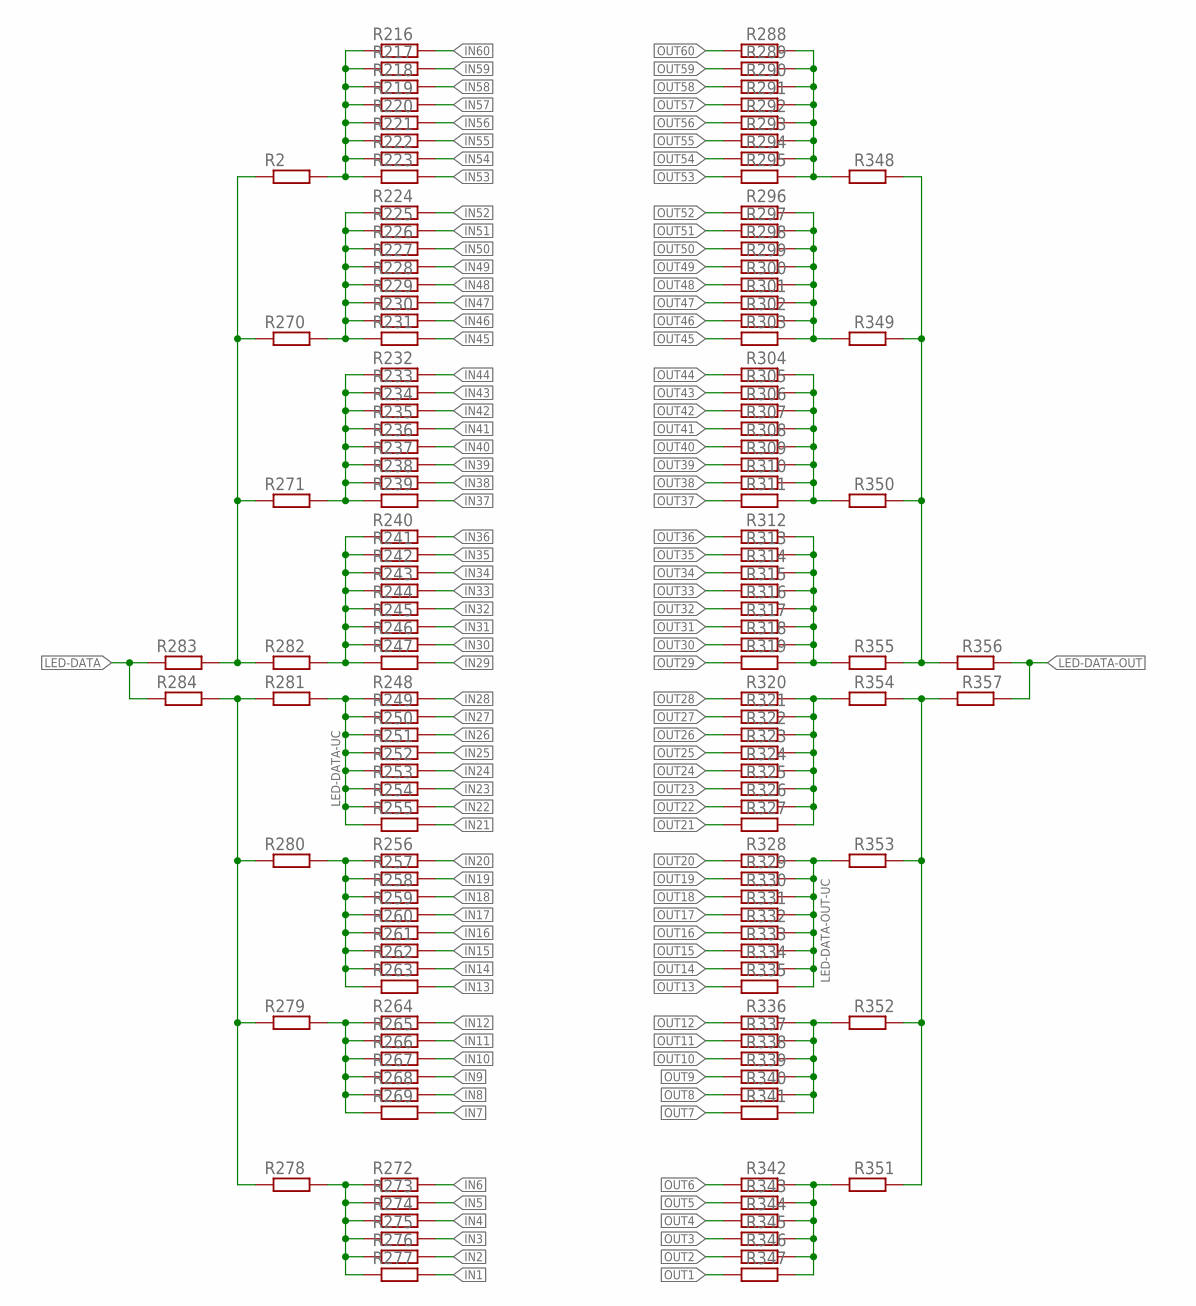
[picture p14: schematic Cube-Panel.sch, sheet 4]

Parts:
R2, R216, R217, R218, R219, R220, R221, R222, R223, R224, R225, R226, R227, R228, R229, R230, R231, R232, R233, R234, R235, R236, R237, R238, R239, R240, R241, R242, R243, R244, R245, R246, R247, R248, R249, R250, R251, R252, R253, R254, R255, R256, R257, R258, R259, R260, R261, R262, R263, R264, R265, R266, R267, R268, R269, R270, R271, R272, R273, R274, R275, R276, R277, R278, R279, R280, R281, R282, R283, R284, R288, R289, R290, R291, R292, R293, R294, R295, R296, R297, R298, R299, R300, R301, R302, R303, R304, R305, R306, R307, R308, R309, R310, R311, R312, R313, R314, R315, R316, R317, R318, R319, R320, R321, R322, R323, R324, R325, R326, R327, R328, R329, R330, R331, R332, R333, R334, R335, R336, R337, R338, R339, R340, R341, R342, R343, R344, R345, R346, R347, R348, R349, R350, R351, R352, R353, R354, R355, R356, R357: WIDERSTAND-0603; 0603

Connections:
IN1: R277.P$2 (2); also elsewhere on the board
IN2: R276.P$2 (2); also elsewhere on the board
IN3: R275.P$2 (2); also elsewhere on the board
IN4: R274.P$2 (2); also elsewhere on the board
IN5: R273.P$2 (2); also elsewhere on the board
IN6: R272.P$2 (2); also elsewhere on the board
IN7: R269.P$2 (2); also elsewhere on the board
IN8: R268.P$2 (2); also elsewhere on the board
IN9: R267.P$2 (2); also elsewhere on the board
IN10: R266.P$2 (2); also elsewhere on the board
IN11: R265.P$2 (2); also elsewhere on the board
IN12: R264.P$2 (2); also elsewhere on the board
IN13: R263.P$2 (2); also elsewhere on the board
IN14: R262.P$2 (2); also elsewhere on the board
IN15: R261.P$2 (2); also elsewhere on the board
IN16: R260.P$2 (2); also elsewhere on the board
IN17: R259.P$2 (2); also elsewhere on the board
IN18: R258.P$2 (2); also elsewhere on the board
IN19: R257.P$2 (2); also elsewhere on the board
IN20: R256.P$2 (2); also elsewhere on the board
IN21: R255.P$2 (2); also elsewhere on the board
IN22: R254.P$2 (2); also elsewhere on the board
IN23: R253.P$2 (2); also elsewhere on the board
IN24: R252.P$2 (2); also elsewhere on the board
IN25: R251.P$2 (2); also elsewhere on the board
IN26: R250.P$2 (2); also elsewhere on the board
IN27: R249.P$2 (2); also elsewhere on the board
IN28: R248.P$2 (2); also elsewhere on the board
IN29: R247.P$2 (2); also elsewhere on the board
IN30: R246.P$2 (2); also elsewhere on the board
IN31: R245.P$2 (2); also elsewhere on the board
IN32: R244.P$2 (2); also elsewhere on the board
IN33: R243.P$2 (2); also elsewhere on the board
IN34: R242.P$2 (2); also elsewhere on the board
IN35: R241.P$2 (2); also elsewhere on the board
IN36: R240.P$2 (2); also elsewhere on the board
IN37: R239.P$2 (2); also elsewhere on the board
IN38: R238.P$2 (2); also elsewhere on the board
IN39: R237.P$2 (2); also elsewhere on the board
IN40: R236.P$2 (2); also elsewhere on the board
IN41: R235.P$2 (2); also elsewhere on the board
IN42: R234.P$2 (2); also elsewhere on the board
IN43: R233.P$2 (2); also elsewhere on the board
IN44: R232.P$2 (2); also elsewhere on the board
IN45: R231.P$2 (2); also elsewhere on the board
IN46: R230.P$2 (2); also elsewhere on the board
IN47: R229.P$2 (2); also elsewhere on the board
IN48: R228.P$2 (2); also elsewhere on the board
IN49: R227.P$2 (2); also elsewhere on the board
IN50: R226.P$2 (2); also elsewhere on the board
IN51: R225.P$2 (2); also elsewhere on the board
IN52: R224.P$2 (2); also elsewhere on the board
IN53: R223.P$2 (2); also elsewhere on the board
IN54: R222.P$2 (2); also elsewhere on the board
IN55: R221.P$2 (2); also elsewhere on the board
IN56: R220.P$2 (2); also elsewhere on the board
IN57: R219.P$2 (2); also elsewhere on the board
IN58: R218.P$2 (2); also elsewhere on the board
IN59: R217.P$2 (2); also elsewhere on the board
IN60: R216.P$2 (2); also elsewhere on the board
LED-DATA: R283.P$1 (1), R284.P$1 (1); also elsewhere on the board
LED-DATA-OUT: R356.P$1 (1), R357.P$1 (1); also elsewhere on the board
LED-DATA-OUT-UC: R328.P$1 (1), R329.P$1 (1), R330.P$1 (1), R331.P$1 (1), R332.P$1 (1), R333.P$1 (1), R334.P$1 (1), R335.P$1 (1), R353.P$2 (2); also elsewhere on the board
LED-DATA-UC: R248.P$1 (1), R249.P$1 (1), R250.P$1 (1), R251.P$1 (1), R252.P$1 (1), R253.P$1 (1), R254.P$1 (1), R255.P$1 (1), R281.P$2 (2); also elsewhere on the board
unnamed: R278.P$1 (1), R279.P$1 (1), R280.P$1 (1), R281.P$1 (1), R284.P$2 (2)
unnamed: R2.P$1 (1), R270.P$1 (1), R271.P$1 (1), R282.P$1 (1), R283.P$2 (2)
unnamed: R288.P$1 (1), R289.P$1 (1), R290.P$1 (1), R291.P$1 (1), R292.P$1 (1), R293.P$1 (1), R294.P$1 (1), R295.P$1 (1), R348.P$2 (2)
unnamed: R296.P$1 (1), R297.P$1 (1), R298.P$1 (1), R299.P$1 (1), R300.P$1 (1), R301.P$1 (1), R302.P$1 (1), R303.P$1 (1), R349.P$2 (2)
unnamed: R304.P$1 (1), R305.P$1 (1), R306.P$1 (1), R307.P$1 (1), R308.P$1 (1), R309.P$1 (1), R310.P$1 (1), R311.P$1 (1), R350.P$2 (2)
unnamed: R312.P$1 (1), R313.P$1 (1), R314.P$1 (1), R315.P$1 (1), R316.P$1 (1), R317.P$1 (1), R318.P$1 (1), R319.P$1 (1), R355.P$2 (2)
unnamed: R320.P$1 (1), R321.P$1 (1), R322.P$1 (1), R323.P$1 (1), R324.P$1 (1), R325.P$1 (1), R326.P$1 (1), R327.P$1 (1), R354.P$2 (2)
unnamed: R2.P$2 (2), R216.P$1 (1), R217.P$1 (1), R218.P$1 (1), R219.P$1 (1), R220.P$1 (1), R221.P$1 (1), R222.P$1 (1), R223.P$1 (1)
unnamed: R336.P$1 (1), R337.P$1 (1), R338.P$1 (1), R339.P$1 (1), R340.P$1 (1), R341.P$1 (1), R352.P$2 (2)
unnamed: R342.P$1 (1), R343.P$1 (1), R344.P$1 (1), R345.P$1 (1), R346.P$1 (1), R347.P$1 (1), R351.P$2 (2)
unnamed: R351.P$1 (1), R352.P$1 (1), R353.P$1 (1), R354.P$1 (1), R357.P$2 (2)
unnamed: R348.P$1 (1), R349.P$1 (1), R350.P$1 (1), R355.P$1 (1), R356.P$2 (2)
unnamed: R224.P$1 (1), R225.P$1 (1), R226.P$1 (1), R227.P$1 (1), R228.P$1 (1), R229.P$1 (1), R230.P$1 (1), R231.P$1 (1), R270.P$2 (2)
unnamed: R232.P$1 (1), R233.P$1 (1), R234.P$1 (1), R235.P$1 (1), R236.P$1 (1), R237.P$1 (1), R238.P$1 (1), R239.P$1 (1), R271.P$2 (2)
unnamed: R240.P$1 (1), R241.P$1 (1), R242.P$1 (1), R243.P$1 (1), R244.P$1 (1), R245.P$1 (1), R246.P$1 (1), R247.P$1 (1), R282.P$2 (2)
unnamed: R256.P$1 (1), R257.P$1 (1), R258.P$1 (1), R259.P$1 (1), R260.P$1 (1), R261.P$1 (1), R262.P$1 (1), R263.P$1 (1), R280.P$2 (2)
unnamed: R264.P$1 (1), R265.P$1 (1), R266.P$1 (1), R267.P$1 (1), R268.P$1 (1), R269.P$1 (1), R279.P$2 (2)
unnamed: R272.P$1 (1), R273.P$1 (1), R274.P$1 (1), R275.P$1 (1), R276.P$1 (1), R277.P$1 (1), R278.P$2 (2)
OUT1: R347.P$2 (2); also elsewhere on the board
OUT2: R346.P$2 (2); also elsewhere on the board
OUT3: R345.P$2 (2); also elsewhere on the board
OUT4: R344.P$2 (2); also elsewhere on the board
OUT5: R343.P$2 (2); also elsewhere on the board
OUT6: R342.P$2 (2); also elsewhere on the board
OUT7: R341.P$2 (2); also elsewhere on the board
OUT8: R340.P$2 (2); also elsewhere on the board
OUT9: R339.P$2 (2); also elsewhere on the board
OUT10: R338.P$2 (2); also elsewhere on the board
OUT11: R337.P$2 (2); also elsewhere on the board
OUT12: R336.P$2 (2); also elsewhere on the board
OUT13: R335.P$2 (2); also elsewhere on the board
OUT14: R334.P$2 (2); also elsewhere on the board
OUT15: R333.P$2 (2); also elsewhere on the board
OUT16: R332.P$2 (2); also elsewhere on the board
OUT17: R331.P$2 (2); also elsewhere on the board
OUT18: R330.P$2 (2); also elsewhere on the board
OUT19: R329.P$2 (2); also elsewhere on the board
OUT20: R328.P$2 (2); also elsewhere on the board
OUT21: R327.P$2 (2); also elsewhere on the board
OUT22: R326.P$2 (2); also elsewhere on the board
OUT23: R325.P$2 (2); also elsewhere on the board
OUT24: R324.P$2 (2); also elsewhere on the board
OUT25: R323.P$2 (2); also elsewhere on the board
OUT26: R322.P$2 (2); also elsewhere on the board
OUT27: R321.P$2 (2); also elsewhere on the board
OUT28: R320.P$2 (2); also elsewhere on the board
OUT29: R319.P$2 (2); also elsewhere on the board
OUT30: R318.P$2 (2); also elsewhere on the board
OUT31: R317.P$2 (2); also elsewhere on the board
OUT32: R316.P$2 (2); also elsewhere on the board
OUT33: R315.P$2 (2); also elsewhere on the board
OUT34: R314.P$2 (2); also elsewhere on the board
OUT35: R313.P$2 (2); also elsewhere on the board
OUT36: R312.P$2 (2); also elsewhere on the board
OUT37: R311.P$2 (2); also elsewhere on the board
OUT38: R310.P$2 (2); also elsewhere on the board
OUT39: R309.P$2 (2); also elsewhere on the board
OUT40: R308.P$2 (2); also elsewhere on the board
OUT41: R307.P$2 (2); also elsewhere on the board
OUT42: R306.P$2 (2); also elsewhere on the board
OUT43: R305.P$2 (2); also elsewhere on the board
OUT44: R304.P$2 (2); also elsewhere on the board
OUT45: R303.P$2 (2); also elsewhere on the board
OUT46: R302.P$2 (2); also elsewhere on the board
OUT47: R301.P$2 (2); also elsewhere on the board
OUT48: R300.P$2 (2); also elsewhere on the board
OUT49: R299.P$2 (2); also elsewhere on the board
OUT50: R298.P$2 (2); also elsewhere on the board
OUT51: R297.P$2 (2); also elsewhere on the board
OUT52: R296.P$2 (2); also elsewhere on the board
OUT53: R295.P$2 (2); also elsewhere on the board
OUT54: R294.P$2 (2); also elsewhere on the board
OUT55: R293.P$2 (2); also elsewhere on the board
OUT56: R292.P$2 (2); also elsewhere on the board
OUT57: R291.P$2 (2); also elsewhere on the board
OUT58: R290.P$2 (2); also elsewhere on the board
OUT59: R289.P$2 (2); also elsewhere on the board
OUT60: R288.P$2 (2); also elsewhere on the board

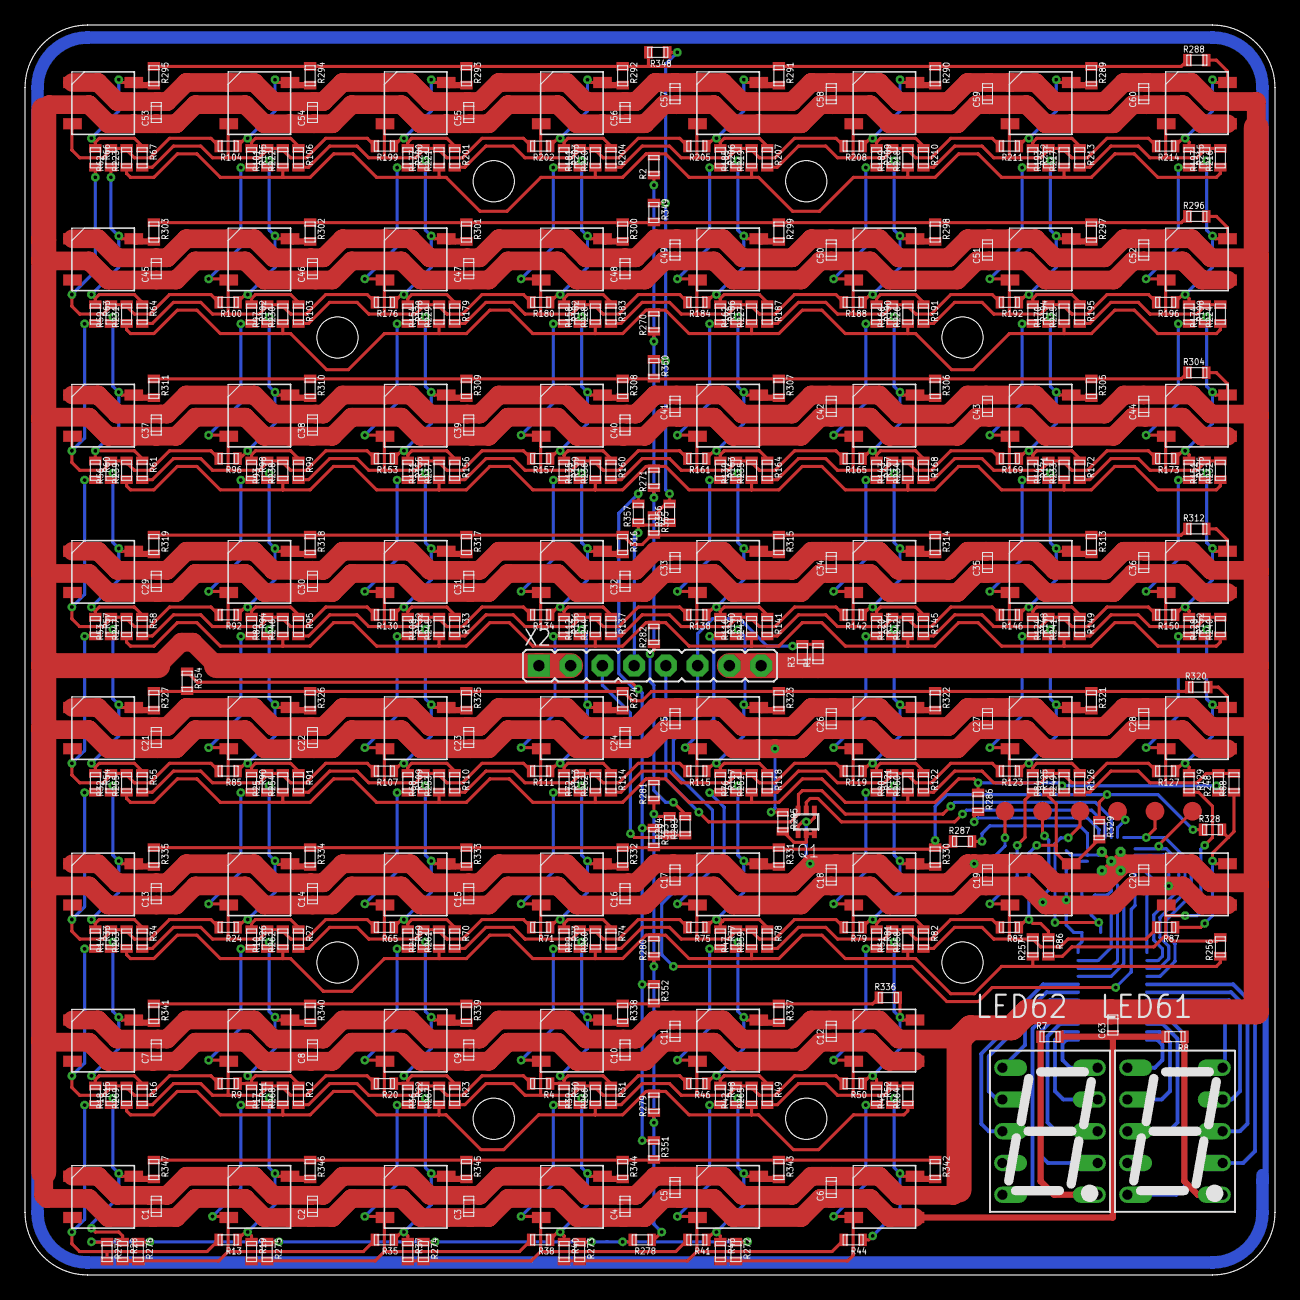
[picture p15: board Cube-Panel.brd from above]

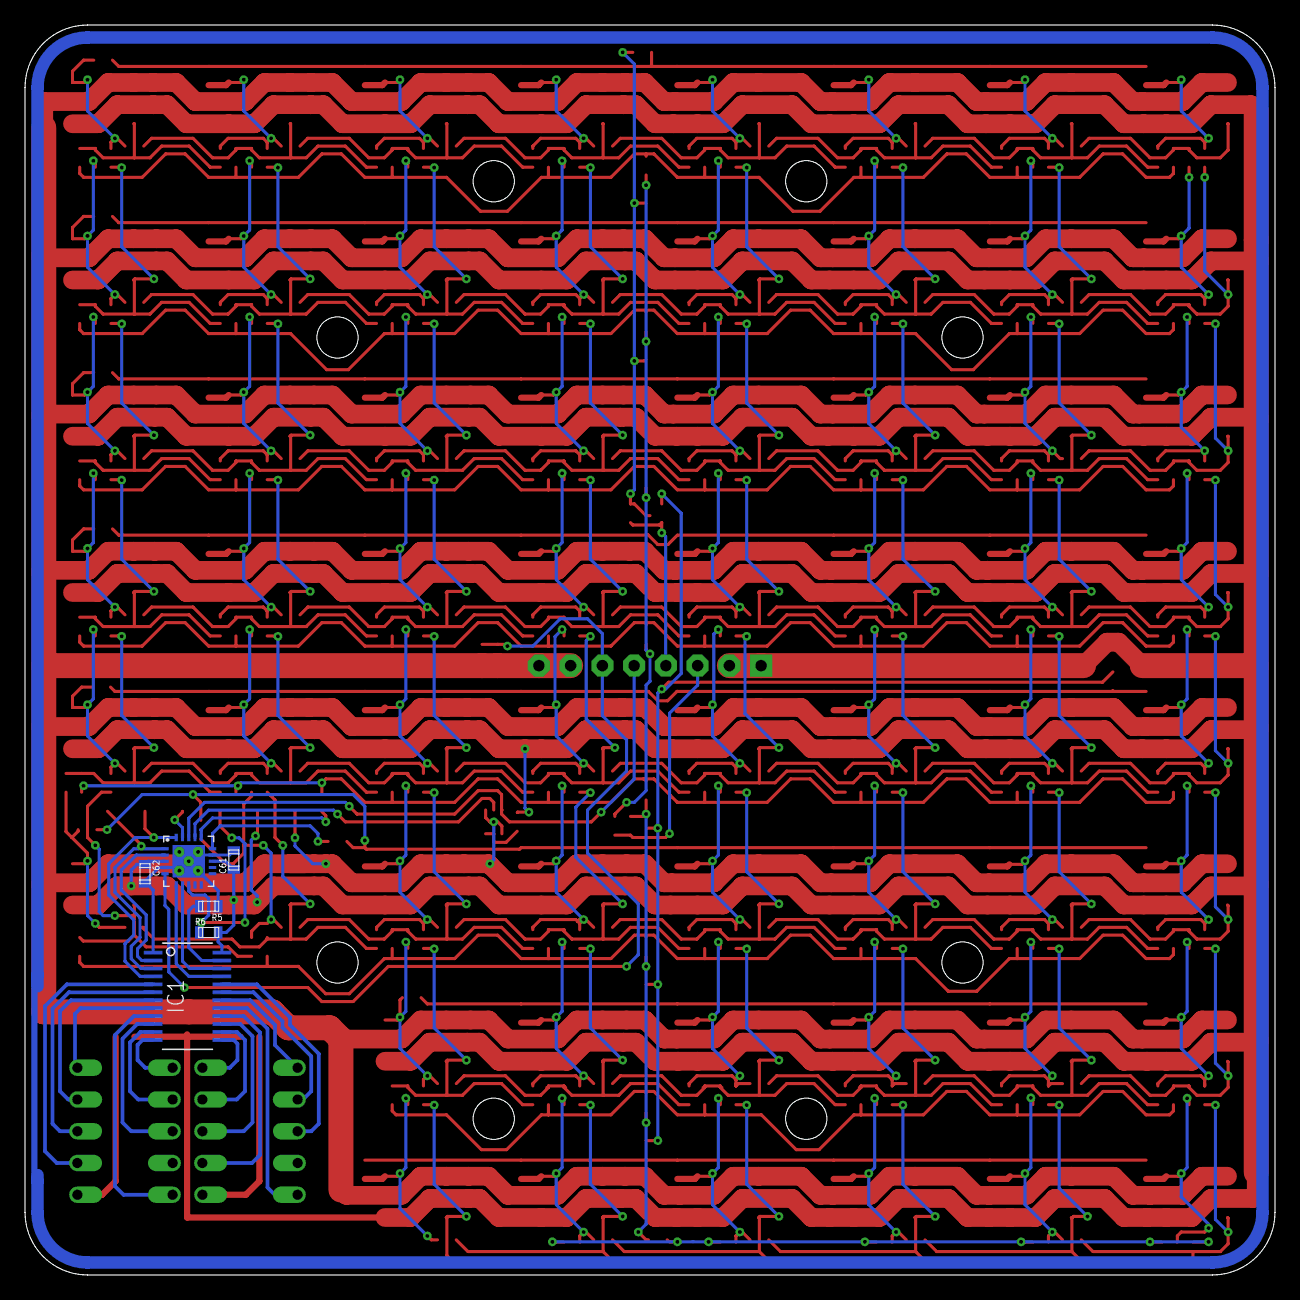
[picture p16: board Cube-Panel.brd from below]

Board: 2 copper layers, 100.0 x 100.0 mm, 492 parts (6 on the bottom side), 176 nets.

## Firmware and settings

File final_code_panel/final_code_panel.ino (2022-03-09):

#include <ESP8266WiFi.h>
#include <Adafruit_NeoPixel.h>
#include <SoftwareSerial.h>
#include "./final_code_panel_header.h"

SoftwareSerial Kbus(D1, D0);
Adafruit_NeoPixel strip = Adafruit_NeoPixel(100, D5, NEO_GRB + NEO_KHZ800);

uint8_t led_count[8] = {8, 10, 12, 10, 7, 14, 14, 8};
uint8_t led_sum = 0, led_sum_max = 0;
uint8_t panels = 0x81;
uint8_t analog[6] = {0};

uint8_t respTry = 0;
uint8_t respPanel = 0;
void handleKbus(Stream *stream);
void checkKbusMessage(char *msg);
void checkKbusDevices(void);
void checkKbusDevice(uint8_t panelNr);

StaticJsonDocument<300> doc;

// ______________________________________________________________________
void setup() {
  Serial.begin(115200);
  Kbus.begin(4800);
  
  strip.begin();
  
  for (int x=0; x<100; x++) {
    strip.setPixelColor(x, 0, 0, 0);
  }

  strip.show();
  
  for(uint8_t i=0; i<sizeof(led_count); i++) {
    led_sum_max += led_count[i];
  }
  Kbus.println("D1=__");
  delay(50);
  Kbus.println("D2=__");
  delay(50);
  Kbus.println("D3=__");
  delay(50);
  Kbus.println("D4=__");
  delay(50);
  Kbus.println("D5=__");
  delay(50);
  Kbus.println("D6=__");
  delay(50);
  
  Serial.println("Setup except for MQTT done");

  /*********************
     WiFi Connection
   *********************/
  Serial.print("Connecting to ");
  Serial.println(SSID);
  // Set name passed to AP while connection
  //  mdns::MDns myMdns();
  WiFi.hostname(NAME);
  // Connect to AP
  WiFi.begin(SSID, PWD);
  // Wait while not connected
  while (WiFi.status() != WL_CONNECTED) {
    Serial.print(".");
    strip.setPixelColor(0, 0, 0, 50);
    strip.show();
    delay(250);
    strip.setPixelColor(0,0,0,0);
    strip.show();
    delay(250);
  }
  // Print IP
  Serial.println("\nWiFi connected.\nIP Adress: ");
  Serial.println(WiFi.localIP());


  /*********************
     multicast DNS
   *********************/
  // Set name of this device
  if (MDNS.begin(NAME)) {
    Serial.println("Setting up MDNS responder!");
  }
  // The service this device hosts (example)
  MDNS.addService("_escape", "_tcp", 2000);


  /*************************
     Connect to TCP server
   *************************/
  if (client.connect(SERVER_IP, SERVER_PORT)) {
    Serial.println("Connected to server");
  } else {
    Serial.println("Cannot connect to server");
  }

  // OTA setup in separate function
  setupOTA();

  /*************************
     MQTT Setup
   *************************/

  // Set IP and port of broker
  mqtt.setServer(MQTT_SERVER_IP, MQTT_PORT);
  // Set CB function to be called for all subscriptions
  mqtt.setCallback(mqttCallback);
  // Connect to broker using a unique ID (here the name)
  if (mqtt.connect(NAME)) {
    Serial.println("Connected to MQTT server");
    // Subscribe to a certain topic
    mqtt.subscribe("1/#");
  } else {
    Serial.println("Cannot connect to MQTT server");
  }

  // Indicate end of setup
  Serial.println("Setup for MQTT done!");

  
  delay(100);
}


// ______________________________________________________________________
int8_t led = 0;
uint8_t curr_panel = 0;
char KbusBuffer[20] = {0};
uint8_t KbusPtr = 0;
void loop () {

  // MQTT Code
  // Needs to be called to check for external update request
  ArduinoOTA.handle();
  // Checks for MQTT subscriptions
  mqtt.loop();

  // Change state from idle to active afterwards cycle between
  if (puzzleState != puzzleStatePrev){
    // solved and active
    if (puzzleState == idle) {
      puzzleIdle();
      puzzleStatePrev = idle;
    } else if (puzzleState == activ) {
      puzzleActive();
      puzzleStatePrev = activ;
    } else if (puzzleState == solved){
      puzzleSolved();
      puzzleStatePrev = solved;
    }
  }
  // If at least one byte is available over serial
  if (Serial.available()) {
    handleStream(&Serial);
  }
  
  // If at least one byte is available over TCP
  if (client.available()) {
    handleStream(&client);
  }

  
  if (puzzleState == activ) {
  
    if(Kbus.available()) {
      handleKbus(&Kbus);
    }
    
    if(led == 0) {
      panels = 0x81;
      led_sum = 0;
      curr_panel = 0;
      // Check if all panels are there: @@@
      delay(500);
    }
  
    // Set new Panel and check if next panel exists
    if(respTry == 0 && curr_panel < 8) {
      if(panels&(1<<curr_panel)) {
        // Panel Exists, extend light and ask for next panel
        led_sum += led_count[curr_panel];
        curr_panel++;
        respTry = 7; // Up to 7 Retries of communication.
        checkKbusDevice(curr_panel);
      } else {
        // Panel does not exist, FAIL HERE!
      }
    } else if(respTry >= 0) {
      if(respTry > 0) {
        respTry--;
        checkKbusDevice(curr_panel);
      }
    }
    
    int8_t n = 0;
  
    // Light has reached the end 
    if(led > led_sum_max) {
      // Puzzle finalized, do not do shit.
    } else if(led == led_sum_max) {
      for (int x=0; x<100; x++) {
        strip.setPixelColor(x, 0, 0x0f, 0);
      }
      strip.show();
      Kbus.println("D1=__");
      delay(100);
      Kbus.println("D2=_1.");
      delay(333);
      Kbus.println("D3=_9.");
      delay(333);
      Kbus.println("D4=_5.");
      delay(333);
      Kbus.println("D5=_6.");
      delay(100);
      Kbus.println("D6=__");
      delay(100);
      led++;
      puzzleState = solved;
    } else if(led >= led_sum) {
      uint8_t col = 0x10;
      while(col) {
        col >>= 1;
        for (int x=0; x<led_sum; x++) {
          strip.setPixelColor(x, col, 0, 0);
        }
        led = 0;
        strip.show();
        delay(333);
      }
    }else { 
      // Light is still running
      for (int x=0; x<led_sum; x++) {
        strip.setPixelColor(x, 0);
        //else strip.setPixelColor(x, 0, 0x0f, 0);
      }
      while(n <= led && n < 10) {
        if(led-n < 100) strip.setPixelColor(led-n, (0xff>>n), 0, (0xff>>n));
        n++;
      }
      led = (led+1)%100;
      strip.show();
    }
    
    delay(50);
  } else {
    //Serial.println("Panel Puzzle is inactive");
    delay(1000);
  }
}

void checkKbusMessage(char *msg) {
  uint16_t tmp = 0;
  char thisChar = 0;
  if(*msg == 'X') { // Device available
    if(*(msg+2) == '!' && *(msg+1) >= '0' && *(msg+1) <= '9') panels |= (1<<(*(msg+1)-'0'));
  } else if(*msg == 'A') {
    if(*(msg+1) > '6' || *(msg+1) < '1') return;
    if(*(msg+2) == '=') {
      for(uint8_t i=0; i<3; i++) {
        tmp <<= 4;
        thisChar = *(msg+4+i);
        if(thisChar <= '9' && thisChar >= '0') tmp += thisChar - '0';
        if(thisChar <= 'F' && thisChar >= 'A') tmp += thisChar - 'A' + 10;
      }
      tmp >>= 6;
      analog[*(msg+1)-'1'] = (uint8_t)tmp;
      Serial.print("Panel ");
      Serial.print(*(msg+1));
      Serial.print(", Value: ");
      Serial.println(analog[*(msg+1)-'1']);
      if(*(msg+1) != '0' + curr_panel) return;
      switch(*(msg+1)) { // Check if the module is in the correct place.
        case '1':
          if(tmp >= 0 && tmp <= 1) { panels |= (1<<(*(msg+1)-'0')); respTry = 0; }
          break;
        case '2':
          if(tmp >= 2 && tmp <= 4) { panels |= (1<<(*(msg+1)-'0')); respTry = 0; }
          break;
        case '3':
          if(tmp >= 5 && tmp <= 7) { panels |= (1<<(*(msg+1)-'0')); respTry = 0; }
          break;
        case '4':
          if(tmp >= 8 && tmp <= 10) { panels |= (1<<(*(msg+1)-'0')); respTry = 0; }
          break;
        case '5':
          if(tmp >= 11 && tmp <= 13) { panels |= (1<<(*(msg+1)-'0')); respTry = 0; }
          break;
        case '6':
          if(tmp >= 14 && tmp <= 16) { panels |= (1<<(*(msg+1)-'0')); respTry = 0; }
          break;
          
      }
    }
  } else {
    // We got Blödsinn, retry if neccessary
    if(respTry > 0) {
      respTry--;
      checkKbusDevice(respPanel);
    }
  }
}


void checkKbusDevices(void) {
  panels = 0x81;
  Kbus.println("X1?");
  delay(100);
  Kbus.println("X2?");
  delay(100);
  Kbus.println("X3?");
  delay(100);
  Kbus.println("X4?");
  delay(100);
  Kbus.println("X5?");
  delay(100);
  Kbus.println("X6?");
  delay(100);
}

void checkKbusDevice(uint8_t panelNr) {
  if(panelNr < 1 || panelNr > 6) return;
  respPanel = panelNr;
  panels &= ~(1<<panelNr);
  Kbus.print("A");
  Kbus.print(panelNr);
  Kbus.println("?");
}

void handleStream(Stream * getter) {
  Serial.println("handleStrea");
  // Copy incoming data into msg cstring until newline is received
  snprintf(msg, MSG_SIZE, "%s", getter->readStringUntil('\n').c_str());
  // Some systems also send a carrige return, we want to strip it off
  for (size_t i = 0; i < MSG_SIZE; i++) {
    if (msg[i] == '\r') {
      msg[i] = '\0';
      break;
    }
  }
  // Handle given Msg
  const char * returnMsg = handleMsg(msg, msg, "", "");
  // Write something back to stream only if wanted
  if (returnMsg[0] != '\0') {
    getter->println(returnMsg);
  }
}

void handleKbus(Stream *stream) {
  while(stream->available()) {
    KbusBuffer[KbusPtr] = stream->read();
    Serial.print(KbusBuffer[KbusPtr]);
    if(KbusBuffer[KbusPtr] == '\n') {
      checkKbusMessage(KbusBuffer);
      while(KbusPtr>0) {
        KbusBuffer[KbusPtr] = 0;
        KbusPtr--;
      }
    } else {
      KbusPtr++;
    }
  }
}

/*
   Handle a received topic and message, may return some answer.
*/

const char * handleMsg(const char * state_msg, const char * topic, const char * data, const char * method_msg) {
  // strcmp returns zero on a match
  /*
  if (strcmp(topic, "1/panel/state") == 0 && strcmp(msg, "deactivate") == 0) {
    puzzleIdle();
  } else if (strcmp(topic, "1/panel/state") == 0 && strcmp(msg, "activate") == 0) {
    puzzleActive();
  } else if (strcmp(topic, "1/panel/state") == 0 && strcmp(msg, "solved_panel") == 0) {
    puzzleSolved();
  } else if (strcmp(topic, "1/panel/state") == 0 && strcmp(msg, "reset_panel") == 0) {
    puzzleIdle();
    puzzleState = idle;
  } else {
    return "Unknown command";
  }
  return "";
  */
  if (strcmp(topic, "1/panel/state") == 0 && strcmp(state_msg,"on") == 0 && strcmp(method_msg, "trigger") == 0 && puzzleStatePrev != activ) {
    puzzleActive();
  } else if (strcmp(topic, "1/panel/state")  == 0 && strcmp(state_msg, "off") == 0 && strcmp(method_msg, "trigger") == 0  && strcmp(data, "skipped") == 0 && puzzleStatePrev != solved){
    puzzleSolved();
  } else if (strcmp(topic, "1/panel/state")  == 0 && strcmp(state_msg, "off") == 0 && strcmp(method_msg, "trigger") == 0 && puzzleStatePrev != idle) {
    puzzleIdle();
  } else {
    return "Unknown command";
  }
  return "";
}


/*
   Puzzle changes to idle state
*/

void puzzleIdle() {
  puzzleState = idle;
  // Code to puzzle state idle...
  // Serial.println("Idle State");
  puzzleStateChanged();
  //mqtt_publish("game/puzzle1", "status", "off");
  puzzleState = idle;
  led = 0;
  led_sum = 0;
  led_sum_max = 0;
  panels = 0x81;
  for (int x=0; x<100; x++) {
    strip.setPixelColor(x, 0, 0, 0);
  }
  strip.show();

  for(uint8_t i=0; i<sizeof(led_count); i++) {
    led_sum_max += led_count[i];
  }
  // Reset Displays, do it twice to play it safe.
  for(uint8_t i=0; i<2; i++) {
    Kbus.println("D1=__");
    delay(75);
    Kbus.println("D2=__");
    delay(75);
    Kbus.println("D3=__");
    delay(75);
    Kbus.println("D4=__");
    delay(75);
    Kbus.println("D5=__");
    delay(75);
    Kbus.println("D6=__");
    delay(75);    
  }

  mqtt_publish("1/panel/state","status", "off");
}


/*
   Puzzle changes to active state
*/

void puzzleActive() {
  puzzleState = activ;
  // Code to set puzzle into active state ...
  // Serial.println("Active State");
  puzzleStateChanged();
  mqtt_publish("1/panel/state","status", "on");
  //mqtt_publish("game/puzzle1", "status", "on");
}


/*
   Puzzle changes to solved state
*/

void puzzleSolved() {
  puzzleState = solved;
  // Code to set puzzle into solved state ...
  // Serial.println("Solved State");
  puzzleStateChanged();
  mqtt_publish("1/panel/state","status", "solved");
  mqtt_publish("game/puzzle1", "Solved", "");
  //mqtt_publish("1/panel/state", "status", "activate");
}



/*
   Indicate to others that the state of the
   puzzle changed
*/

void puzzleStateChanged() {
  Serial.printf("Puzzle state changed to: %s\n", puzzleStateToStr(puzzleState));

  // Convert puzzlestate into JSON dict
  JsonObject obj = dict.to<JsonObject>();
  obj.clear();
  obj["state"] = puzzleStateToStr(puzzleState);
  // Serialize into msg cstring
  serializeJson(obj, msg);

  // If the TCP client is connected to the server, send JSON
  if (client.connected()) {
    client.println(msg);
  }
  // If the MQTT client is connected to broker, send JSON
  if (mqtt.connected()) {
    // Specify if msg should be retained
    bool retained = true;
    // Publish msg under given topic
    mqtt.publish("puzzle1/status", ""); //"test", retained);                                                                                                                                                                                                                                                                                                                                           , retained);
  }
}


/*
   Convert the ENUM to a string
*/

const char * puzzleStateToStr(PuzzleState puzzle) {
  switch (puzzle) {
    case activ: return "active";
    case idle: return "idle";
    case solved: return "solved";
    default: return "Unknown state";
  }
}


/*
   Setup OTA Updates
*/

void setupOTA() {
  // Set name of this device (again)
  ArduinoOTA.setHostname(NAME);
  // Set a password to protect against uploads from other parties
  ArduinoOTA.setPassword(OTA_PWD);

  // CB function for when update starts
  ArduinoOTA.onStart([]() {
    Serial.println("Start updating");
  });
  // CB function for when update starts
  ArduinoOTA.onEnd([]() {
    Serial.println("Finished updating");
  });
  // CB function for progress
  ArduinoOTA.onProgress([](unsigned int progress, unsigned int total) {
    Serial.printf("Update at %u % \n", progress / (total / 100));
  });
  // CB function for when update was interrupted
  ArduinoOTA.onError([](ota_error_t error) {
    Serial.println("Error updating");
    ESP.restart();
  });
  // Start OTA update service
  ArduinoOTA.begin();
}


/*
   Callback for MQTT messages on subscribed topics
*/

void mqttCallback(char* topic, byte* message, unsigned int length) {
  // Convert message as byte array to cstring
  unsigned int len = min((int)length, (int)(MSG_SIZE - 1));
  memcpy(&msg[0], message, len);
  msg[len] = '\0';
  // Print over serial
  Serial.printf("MQTT msg on topic: %s: %s\n", topic, &msg);

  // Try to deserialize the JSON msg
  DeserializationError error = deserializeJson(dict, msg);
  // Test if parsing succeeds.
  if (error) {
    Serial.println("error deserializing the msg");
  } else {
    Serial.println("Msg is of valid JSON format");
    // Try to extract new state
    const char* method_msg = dict["method"];
    const char* newState = dict["state"];
    const char* data_msg = dict["data"];
    if (!data_msg) {
      data_msg = "None";
    }
    if (!method_msg) {
      method_msg = "None";
    }
    // If key exists this is not NULL
    if (newState) {
      handleMsg(newState, topic, data_msg, method_msg);
    }
  }
}

void mqtt_publish(const char* topic, const char* method_, const char* state){
  doc["method"] = method_;
  doc["state"] = state;
  doc["data"] = 0;

  char JSONmessageBuffer[100];

  serializeJson(doc,JSONmessageBuffer, 100);
  mqtt.publish(topic, JSONmessageBuffer,true);
}

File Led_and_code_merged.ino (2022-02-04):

#include <Adafruit_NeoPixel.h>
#include<Wire.h>
//#include <ESP8266WiFi.h>

//char *ssid = "BV9900Pro";
char *ssid = "Mi 11 Lite";
char *password = "ff799896820f";
const uint8_t MPU_address= 104; // the one from uni has 40, the one from Kevin has 104

Adafruit_NeoPixel strip = Adafruit_NeoPixel(67, D5, NEO_GRB + NEO_KHZ800);

uint8_t upside, upside_old = -1, upside_duration;

int snake[70] = {0};
int reset = 21;

uint8_t sequence[6] = {2,6,4,3,5,1};
uint8_t seq_cntr = 0;
uint8_t moved = 0;

// ______________________________________________________________________
void setup() {
  Wire.begin();
  Serial.begin(115200);

  /*
  Serial.println("\nHowdy!");

  // initialize WIFI
  WiFi.mode(WIFI_STA);
  WiFi.begin(ssid, password);
  Serial.println("\nConnecting");

  while(WiFi.status() != WL_CONNECTED){
    Serial.print(".");
    delay(500);
  }

  Serial.println("\nConnected to the WiFi network");
  Serial.print("Local ESP32 IP: ");
  Serial.println(WiFi.localIP());
  */
  
  Wire.beginTransmission(MPU_address);
  Wire.write(0x6B);
  Wire.write(0);
  byte error = Wire.endTransmission();
  if(error) {
    Serial.print("ERROR, when trying to connect to the device. Error: "); 
    Serial.println(error);
  }
  
  // set sensitivity to +- 2g
  Wire.beginTransmission(MPU_address);
  Wire.write(0x1C);
  Wire.write(0b00000000); 
  Wire.endTransmission();

  strip.begin();
  for (int x=0; x<67; x++) {
    strip.setPixelColor(x, 0);
  }
  strip.show();
  Serial.println("Setup done");
}


// ______________________________________________________________________
int16_t accDefault[3]= {0};
int16_t moveThres = 8196;
void loop () {
  if(moved == 1) glimmer();
  // read acc data
  Wire.beginTransmission(MPU_address);
  Wire.write(0x3B);
  Wire.endTransmission();
  Wire.requestFrom(MPU_address, 6);
  while(Wire.available() < 6);
  int16_t accX_raw = Wire.read() << 8 | Wire.read();
  int16_t accY_raw = Wire.read() << 8 | Wire.read();
  int16_t accZ_raw = Wire.read() << 8 | Wire.read();

  uint8_t accDir = 0x70;
  if(accX_raw < 0) {
    accDir &= ~(0x40);
    accX_raw = -accX_raw;
  } 
  if(accY_raw < 0) {
    accDir &= ~(0x20);
    accY_raw = -accY_raw;
  } 
  if(accZ_raw < 0) {
    accDir &= ~(0x10);
    accZ_raw = -accZ_raw;
  }

  if(accX_raw/2 > accY_raw && accX_raw/2 > accZ_raw) accDir |= 0x04;
  else if(accY_raw/2 > accX_raw && accY_raw/2 > accZ_raw) accDir |= 0x02;
  else if(accZ_raw/2 > accX_raw && accZ_raw/2 > accY_raw) accDir |= 0x01;

  if(moved == 0 && accDefault[0] == 0 && accDefault[1] == 0 && accDefault[2] == 0) {
    accDefault[0] = accX_raw;
    accDefault[1] = accY_raw;
    accDefault[2] = accZ_raw;
  } else if(moved == 0 && (accX_raw-accDefault[0] > moveThres || accDefault[0]-accX_raw > moveThres)) {
      moved = 1;
      Serial.println("I was moved!!! *_*");
  }

  // printing raw data
  /*Serial.print(accX_raw); Serial.print("\t");
  Serial.print(accY_raw); Serial.print("\t");
  Serial.print(accZ_raw); Serial.print("\t");
  Serial.print(accDir&0x08); Serial.println("\t");*/
  switch(accDir&0x07) {
    case 0x04:
      upside = (accDir&0x40) ? 5 : 3;
      break;
    case 0x02:
      upside = (accDir&0x20) ? 4 : 2;
      break;
    case 0x01:
      upside = (accDir&0x10) ? 1 : 6;
      break;
    default:
      if(accDir&0x07) upside = 10;
      break;
  }
  if(upside != upside_old) {
    upside_duration = 0;
    upside_old = upside;
  } else if(upside_duration < 20-1) {
    upside_duration++;
  } else if(upside_duration == 20-1) {
    upside_duration++;
    Serial.print("Cube is now on side ");
    Serial.println(upside);

    if(seq_cntr < 6 && moved == 1) {
      if(upside == sequence[seq_cntr]) {
        right(upside-1);
        seq_cntr++;
        if(seq_cntr == 6) Serial.println("Cube has been solved!");
      } else {
        wrong();
        seq_cntr = 0;
      }
    }
    
  }
  // Just some delay to not spam the terminal
  delay(50);
}


// ______________________________________________________________________
int y = 5;
int ydir = 3;
void glimmer() {
  y += ydir;
  if(y >= 70 || y <= 5) ydir = -ydir;
  for (int x=0; x<60; x++) {
    if (snake[x] == 0 and x%2 == 0) {
      strip.setPixelColor(x, y, 0, y);
    }
    if (snake[x] == 0 and x%2 != 0) {
      strip.setPixelColor(x, 75-y, 0, 75-y);
    }
  }
  strip.show();
}


// ______________________________________________________________________
int dickhead_counter = 1;
void wrong() {
  for (int z=0; z<7; z++) {
    for (int x=0; x<60; x++) {
      strip.setPixelColor(x, 50, 0, 0);
      snake[x] = 0;
    }
    strip.show();
    delay(100);
  
    for (int x=0; x<60; x++) {
      strip.setPixelColor(x, 0);
    }
    strip.show();
    delay(100);
  }
  delay(1000*dickhead_counter);
  dickhead_counter++;
  glimmer();
}


// ______________________________________________________________________
void right(int side) {
  /*
   
  for (int x=side*10; x<10*side+10; x++) {
    snake[x] = 1;
  }
  */
  int lstart = 0;
  int lend = 0;

  switch(side){
    case 0:
      lstart = 0;
      lend = 9;
      break;
    case 1:
      lstart = 10;
      lend = 21;
      break;
    case 2:
      lstart = 22;
      lend = 31;
      break;
    case 3:
      lstart = 32;
      lend = 38;
      break;
    case 4:
      lstart = 39;
      lend = 52;
      break;
    case 5:
      lstart = 53;
      lend = 66;
      break;
    default:
      Serial.println("Error");
  }

  for (int x=lstart; x<=lend; x++) {
    snake[x] = 1;
  }

  for (int y=0; y<70; y+=2) {
    for (int x=0; x<67; x++) {
      strip.setPixelColor(x, 0, y, 0);
    }
    strip.show();
    delay(50);
  }

  for (int y=70; y>=0; y-=5) {
    for (int x=0; x<67; x++) {
      strip.setPixelColor(x, 0, y, 0);
    }
    strip.show();
    delay(50);
  }

  for (int x=0; x<67; x++) {
    if (snake[x] == 1) {
      strip.setPixelColor(x, 0, 50, 0);
    }
  }
  strip.show();
}

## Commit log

2021-11-26 Cube-Panel base-design with 7-segment-display and leds.
    [Cube-Panel.brd, Cube-Panel.sch]
2021-11-26 Rerouted power-traces for LEDs so the with increased from 0.75mm to 1.5mm
    [Cube-Panel.brd, Cube-Panel.sch]
2021-11-28 Added Alinas concepts for the cube and the wiring task.
2021-11-28 Moved layout into directory.
    [Cube-Panel.brd, Cube-Panel.sch]
2021-11-28 Added resistors (0603) for path-configurability.
    [Cube-Panel.brd, Cube-Panel.sch]
2021-11-28 Added wired data-path resistors.
    [Cube-Panel.brd, Cube-Panel.sch]
2021-11-29 Added some labels and did some minor aesthetic corrections.
    [Cube-Panel.brd, Cube-Panel.sch]
2021-12-02 Added Select-Resistor for LED#1
    [Cube-Panel.brd, Cube-Panel.sch]
2021-12-03 Added Feedback-Trace for LED-Data. µC can now drive the LEDs. Added Single-Wire-UART-Bus for Communication.
    [Cube-Panel.brd, Cube-Panel.sch]
2021-12-03 µC can now measure its own ID.
    [Cube-Panel.brd, Cube-Panel.sch]
2021-12-08 Layout finalized, hopefully.
    [Cube-Panel.brd, Cube-Panel.sch]
2022-02-03 Sample code to test IMU+LEDs
2022-02-04 merging of code detection and LED feedback
    unfortnately i didn't clone the repository, but copied the code, which is why i can't commit it but have to reupload it...
    [Led_and_code_merged.ino]
2022-02-09 Merging of orientation detection, LED and MQTT
2022-02-11 Corrected KBUS-Pins, Lowered brightness when solved, slowed activation of displays for pin.
    [final_code_panel.ino]
2022-03-04 fixing an mqtt bug
    [final_code_cube.ino]
2023-04-16 changed order of MQTT-Messages, since the order of sending sometimes caused issues, I guess
    [final_code_cube.ino]
